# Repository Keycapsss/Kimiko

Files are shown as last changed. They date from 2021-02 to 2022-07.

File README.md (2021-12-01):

# Kimiko





- Aggressive staggered pinky rows
- Support for one rotary encoder per side (two possible positions)
- Per key RGB led with SK6812 Mini-E led (with legs, easy to solder)
- Support for MX switches (Hotswap sockets)

**[Build-Guide](buildguide_en.md)**

**[Keymap-Guide](Keymap.md)**

**Hardware available at [keycapsss.com](https://keycapsss.com)**

Kimiko keyboard with RGB LED

## Parts

Part name | Quantity | Remarks | Photo |
| ------- | -------- | ------- | ----- |
| Kimiko PCB | 1 set ||
| Kimiko case | 1 set | 2 solid panels, 2 with holes for switches (plates) |
| [Pro Micro](https://keycapsss.com/keyboard-parts/parts/79/arduino-pro-micro-atmega32u4-controller) or [Puchi-C](https://keycapsss.com/keyboard-parts/parts/141/puchi-c-pro-micro-replacement-with-usb-c-and-atmega32u4) | 2 pcs (a mix is possible) | Recommend to  use [Mill-Max Single Row Socket Headers](https://keycapsss.com/keyboard-parts/parts/100/single-row-socket-headers-pins-mill-max-series-315), to make it hot-swappable. ||
| Key switch (MX) | 58-60 pcs |  ||
| [Kailh switch socket](https://keycapsss.com/keyboard-parts/parts/49/kailh-hot-swap-pcb-sockets-10-pcs) | 58-60 pcs |  ||
| Diodes 1N4148W (SMD) | 60 pcs |||
| TRRS jack | 2 pcs ||
| Tactile switch | 2 pcs | Reset switch ||
| TRRS cable | 1 cable | Must be a 4-pole cable ||
| Key caps | 58-60 pcs | 1.5U caps, can also be 1U ||
| Micro USB or USB-C cable | 1 pcs | Dependent what you use on the master half. ||

## Optionally

Part name | Quantity | Remarks | Photo |
| ------- | -------- | ------- | ----- |
| [OLED module](https://keycapsss.com/keyboard-parts/parts/80/ssd1306-oled-lcd-display-0.91-inch-128x32-i2c-white) | 2 pcs | It is possible to use only one display ||
| SK6812 Mini-E | 60 pcs |RGB LEDs for keycap backlight **(underglow LEDs must be soldered, because they are connected in series)** ||
| [Rotary encoder](https://keycapsss.com/keyboard-parts/parts/59/rotary-encoder-with-switch) |0-2 pcs| One per side are supported. |
| [Mill-Max Single Row Socket Headers](https://keycapsss.com/keyboard-parts/parts/100/single-row-socket-headers-pins-mill-max-series-315), or [Spring-loaded pin headers](https://keycapsss.com/keyboard-parts/parts/91/spring-loaded-pin-headers-12-pin-2pcs-conthrough), | 4 x 12 row headers | To make pro micro Hot-swappable. Highly recommended to get the header pins too (You can use diode legs if you don't get the header pins)|

## Case files

Drawings (SVG, DXF) for the case are located in the [plates folder](plates/).

## Firmware

Clone/download the QMK firmware and execute the following in the [qmk_firmware](https://github.com/qmk/qmk_firmware) directory to write the default Lily58L keymap

    make keycapsss/kimiko:default:avrdude (for pro micro) 

When **`Detecting USB port, reset your controller now...`** is displayed, press the reset button on the keyboard to start writing.
Each half of the keyboard must be programmed separately using this approach.

If you're using DFU bootloader (in case of the Puchi-C or Elite-C), replace the 'avrdude' with 'dfu'

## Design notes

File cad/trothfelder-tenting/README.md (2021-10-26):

# Kimiko tenting plates

Basically the same as the offical ones with a little extension.

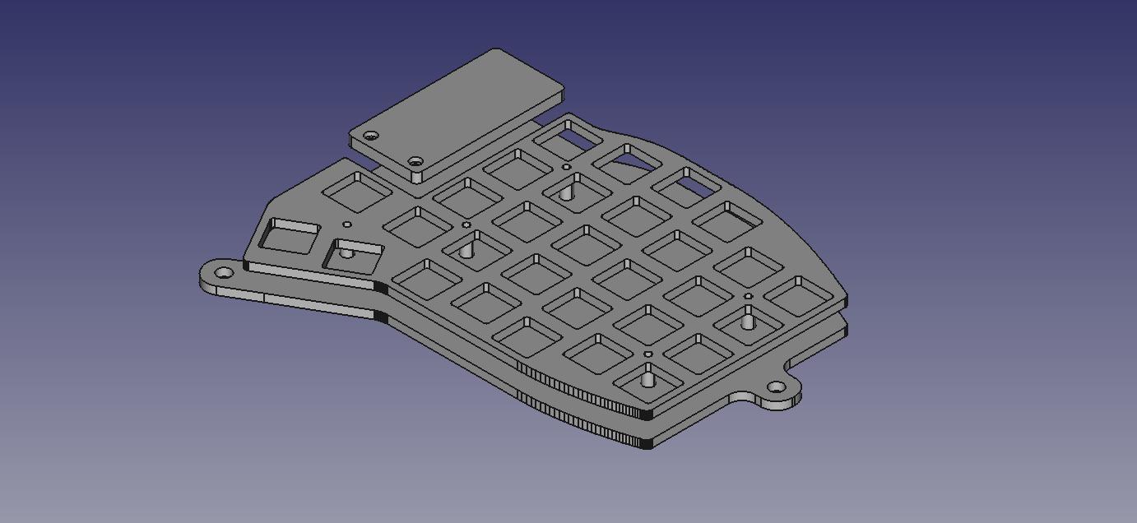
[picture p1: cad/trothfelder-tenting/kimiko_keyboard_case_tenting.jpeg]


The wings on the outside can be use with m5 screws to tent the Kimiko. Adding dipping rubber to the screw heads is a good idea.
I used my cnc mill to cut the plates from 3mm acryllic. The display windowpane is made of 4mm acryllic. In case one wants to cut the windowpane oneself, do not forget to mirror the pane for the second half.
If you want to print the bottom part (the one with the distance holders), do not forget to mirror this part, too. For surface finishing reasons the top part might need to be mirrored in case one wants to print it.
All other parts do not need to be mirrored.

And now a picture of the finished plates:

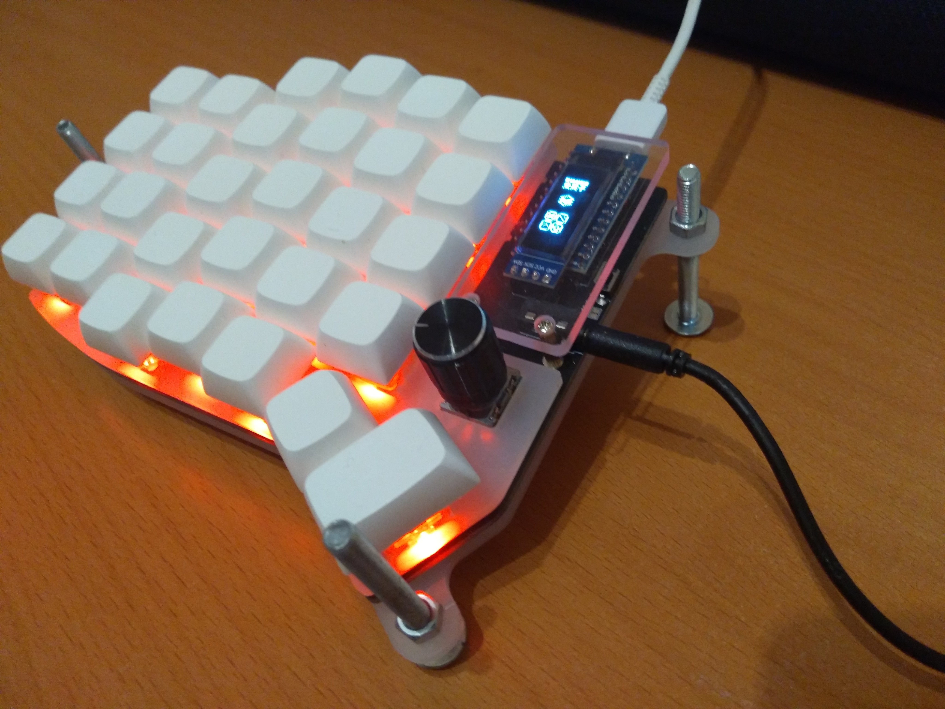
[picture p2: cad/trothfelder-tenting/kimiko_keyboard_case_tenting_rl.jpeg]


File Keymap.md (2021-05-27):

## Default keymap

The [default keymap](https://github.com/qmk/qmk_firmware/blob/master/keyboards/keycapsss/kimiko/keymaps/default/keymap.c) is laid out on the assumption that it will be used in the MacOS/US keyboard environment. Feel free to get creative and experiment with keymaps that match your preferences.

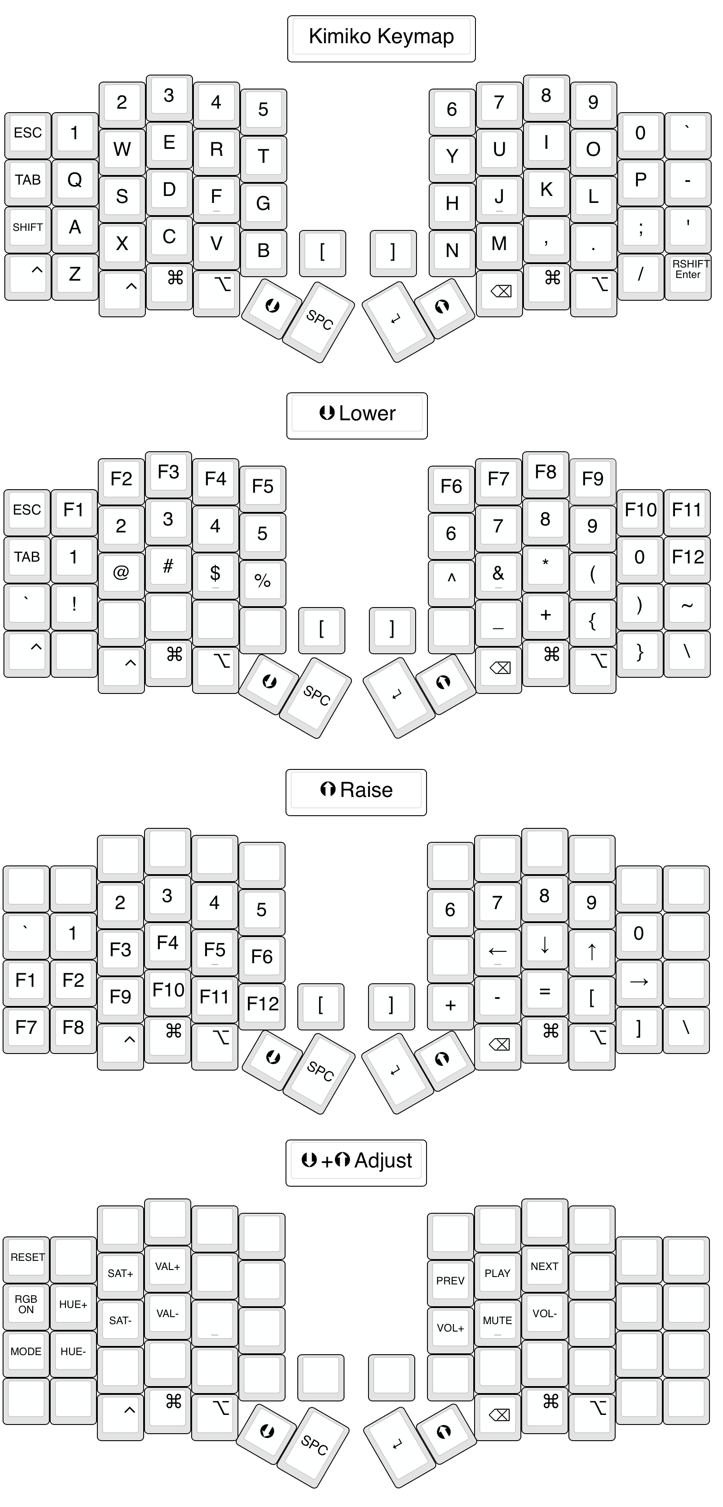
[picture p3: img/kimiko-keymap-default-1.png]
Kimiko default layout


## Customize the default keymap

This self-made keyboard use the QMK firmware, described above. The QMK firmware is highly customizable, and you can unlock a lot functionality simply by editing the keymap.

### Edit keymap.c and customize

When customizing a keymap, start by making a copy of the [`qmk_firmware/keyboards/keycapsss/kimiko/keymaps/default`](https://github.com/qmk/qmk_firmware/blob/master/keyboards/keycapsss/kimiko/keymaps/default/) folder and modifying that directory's internal `keymap.c` file.
Please refer to the [official QMK documentation](https://docs.qmk.fm/#/keycodes) for the key codes and programming specifics.

After changing the keymap,

```bash
make keycapsss/kimiko:default:flash
```

If you get an error, please double-check the board, connection and command.

### Bootloader

**Pro Micro and Puchi-C/Elite-C have different bootloader.** Edit the `rule.mk` file in your keymap folder and add the following line to it.

#### Puchi-C or Elite-C

```c
BOOTLOADER = atmel-dfu
```

#### Pro Micro

```c
BOOTLOADER = caterina
```

If you use the command `make keycapsss/...:flash`, it read the bootloader settings from the `rule.mk` and uses the right flashing software.
If you don't have set the `BOOTLOADER` setting, you can change the command to `make keycapsss/...:caterina` for Pro Micro, or `make keycapsss/...:dfu` for Puchi-C/Elite-C

More information on the [official QMK site](https://beta.docs.qmk.fm/using-qmk/guides/flashing/flashing#atmel-dfu).

### Handedness by EEPROM

You can tell each side of the Keyboard, whether it's left or right, by writing it into it's eeprom.  
In order to do so, first put `#define EE_HANDS` into your config.h.
Then flash the keymap with

```bash
make keycapsss/kimiko:(yourkeymap):avrdude-split-left 
```

and

```bash
make keycapsss/kimiko:(yourkeymap):avrdude-split-right
```

respectively.
If you're using DFU bootloader (in case of the Puchi-C), replace the `avrdude` with `dfu`

From then on, your keyboard will know, which side they are, no matter which side you plug in. You won't have to use the flags again when flashing an update of your keymap.

If you have any problems that aren't answered here, consider joining our discord server at: (<https://discord.gg/5Vfa9azMUr>)

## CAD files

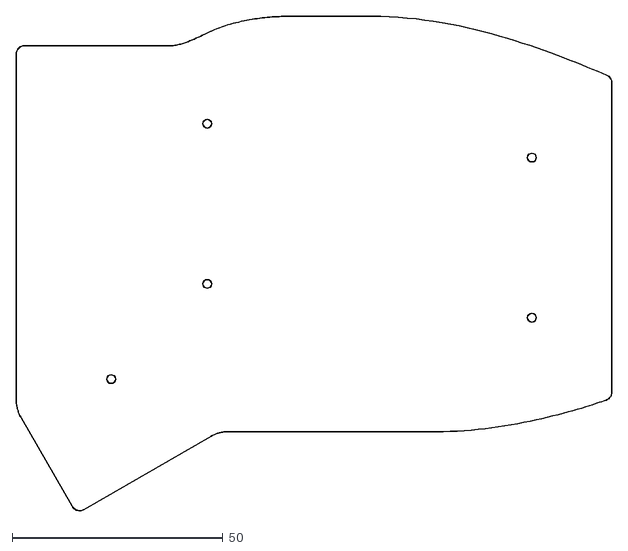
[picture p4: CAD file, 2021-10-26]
cad/benroe-standard-plates/kimiko-plate-bottom.dxf
141.3 x 117.2

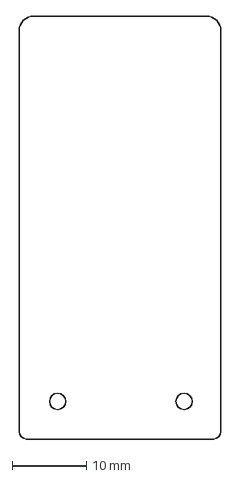
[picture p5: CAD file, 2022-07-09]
cad/plate-guard.dxf
27.3 x 57.1 mm

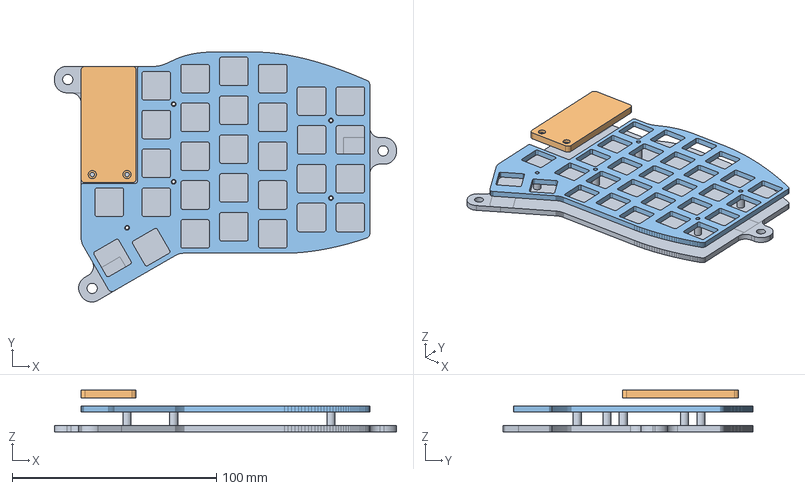
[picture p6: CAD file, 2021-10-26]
cad/trothfelder-tenting/kimiko_keyboard_case_tenting.FCStd
167.4 x 122.4 x 20.4 mm
Bottom
Display
Top

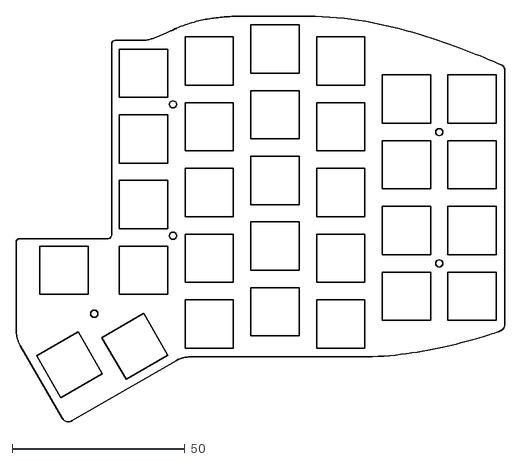
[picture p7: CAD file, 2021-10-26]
cad/benroe-standard-plates/kimiko-plate-top.dxf
141.3 x 117.2

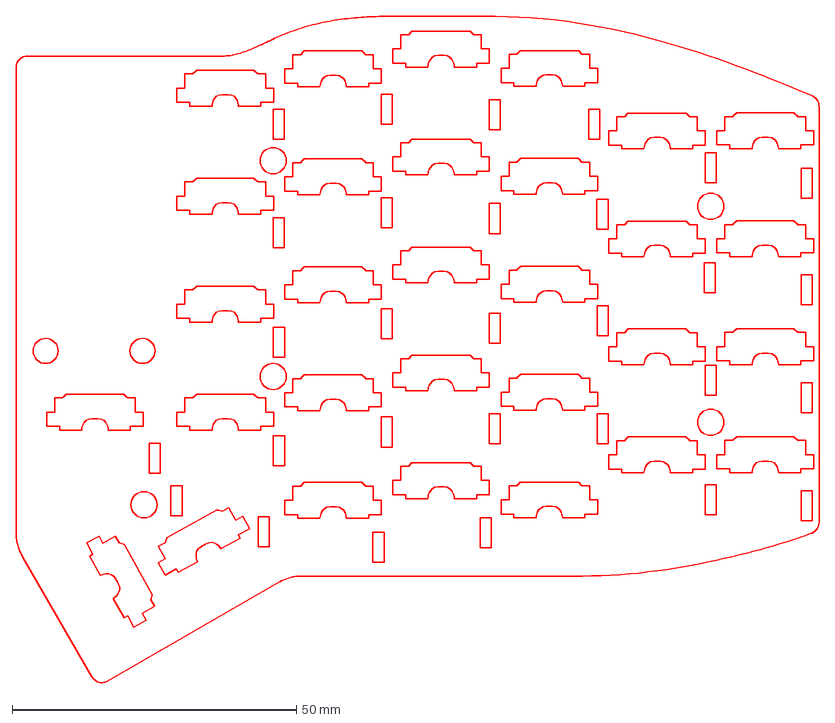
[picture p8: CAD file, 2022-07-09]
cad/foam-bottom.dxf
141.3 x 117.2 mm

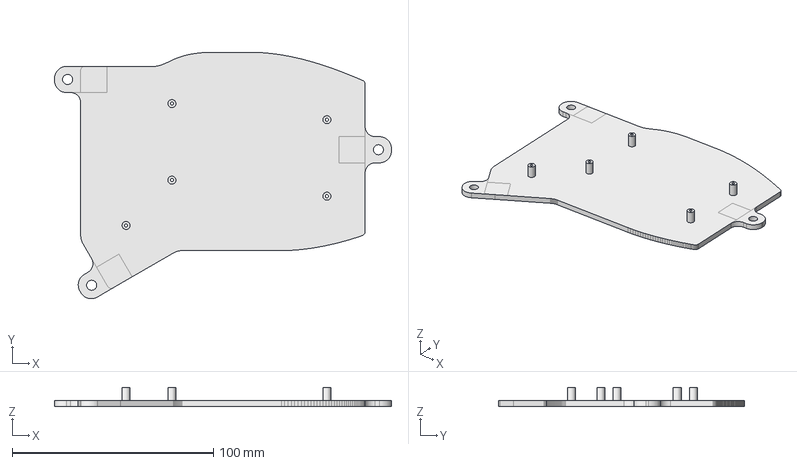
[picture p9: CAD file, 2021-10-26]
cad/trothfelder-tenting/kimiko_keyboard_case_tenting_PartBottom.step
167.4 x 122.4 x 9.60 mm

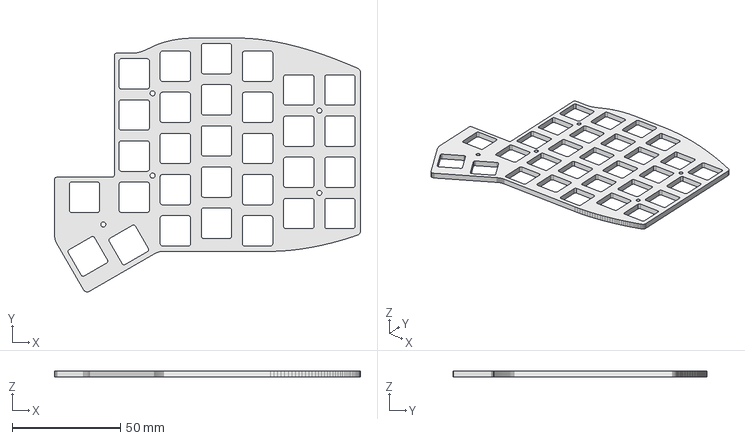
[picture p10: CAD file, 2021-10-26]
cad/trothfelder-tenting/kimiko_keyboard_case_tenting_PartTop.step
141.3 x 117.2 x 3.00 mm

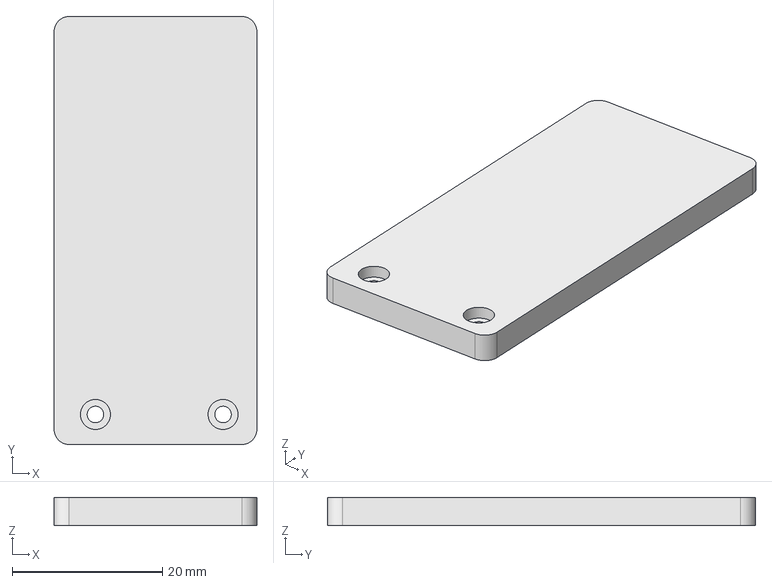
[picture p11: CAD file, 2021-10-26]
cad/trothfelder-tenting/kimiko_keyboard_case_tenting_PartDisplay.step
27.0 x 57.0 x 3.75 mm

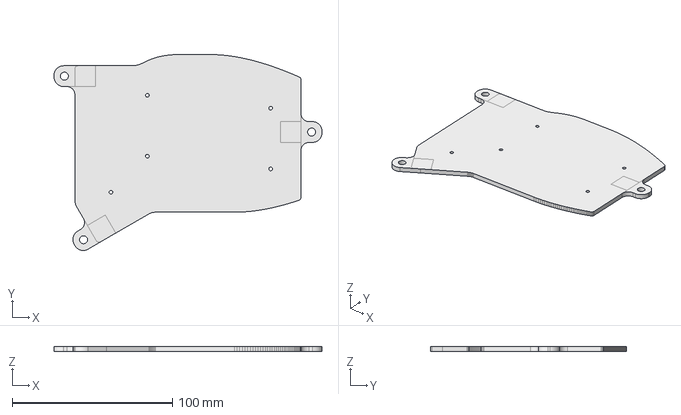
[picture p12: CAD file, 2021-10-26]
cad/trothfelder-tenting/kimiko_keyboard_case_tenting_PartBottom2.step
167.4 x 122.4 x 3.00 mm

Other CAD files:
cad/trothfelder-tenting/kimiko_keyboard_case_tenting.stl
cad/trothfelder-tenting/kimiko_keyboard_case_tenting_PartBottom.stl
cad/trothfelder-tenting/kimiko_keyboard_case_tenting_PartBottom2.stl
cad/trothfelder-tenting/kimiko_keyboard_case_tenting_PartDisplay.stl
cad/trothfelder-tenting/kimiko_keyboard_case_tenting_PartTop.stl

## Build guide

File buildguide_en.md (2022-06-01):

# Kimiko Build Guide





## Required tools

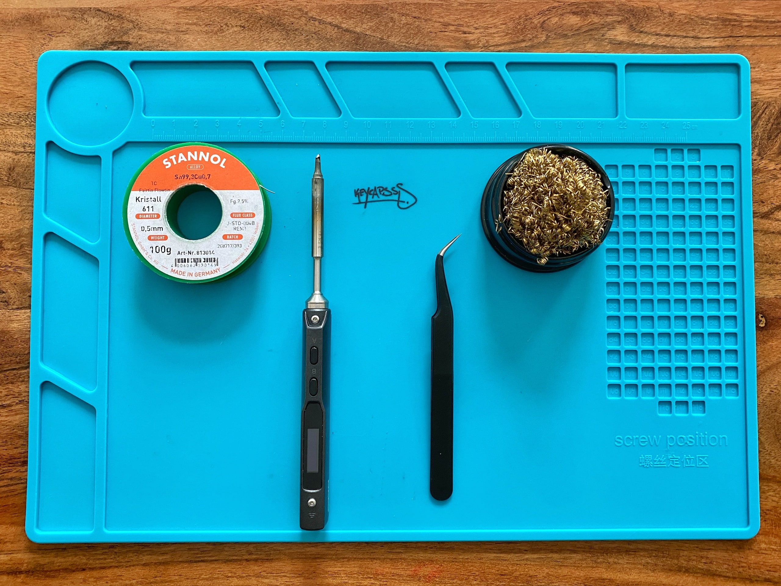
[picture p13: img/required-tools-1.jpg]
Required tools for soldering


* Soldering iron with adjustable temperature
* Solder (i use Sn99.3Cu0.7 0.5mm/0.02inch)
* Tweezers for the small SMD parts
* Tip cleaner (wet sponge or brass wool)
* Side cutters/flush cutters
* Fine pliers

Most parts I solder at 320-340°C. The SMD LEDs are temperature sensitive, so lower the temperature to 300-320°C.

### How to solder tips

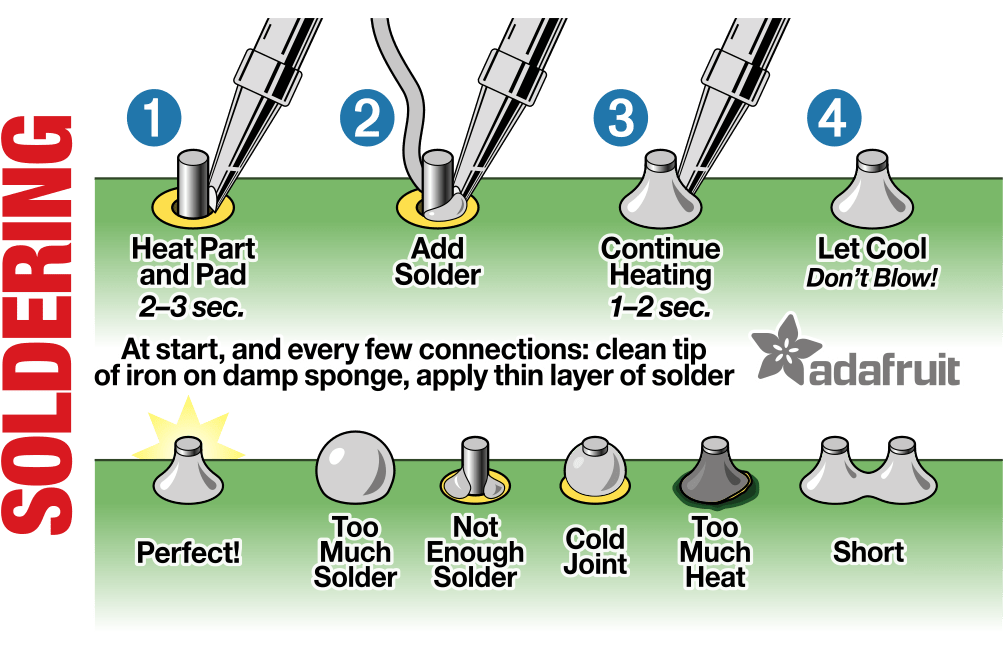
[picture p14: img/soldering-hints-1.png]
How to THT soldering

*[adafruit](https://github.com/adafruit/Reference-Cards)  CC-BY-SA 4.0*

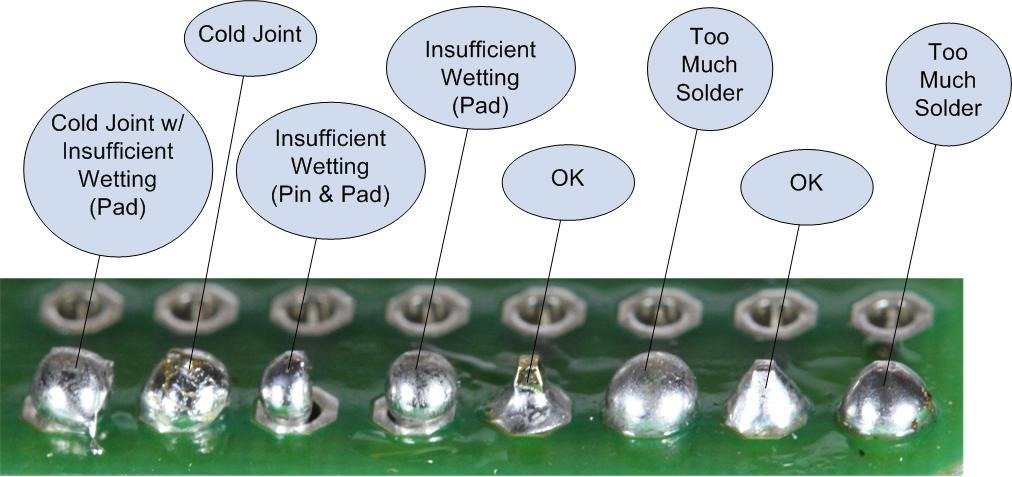
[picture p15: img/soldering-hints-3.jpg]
How to THT soldering

*Source: [adafruit](https://learn.adafruit.com/adafruit-guide-excellent-soldering/common-problems)*

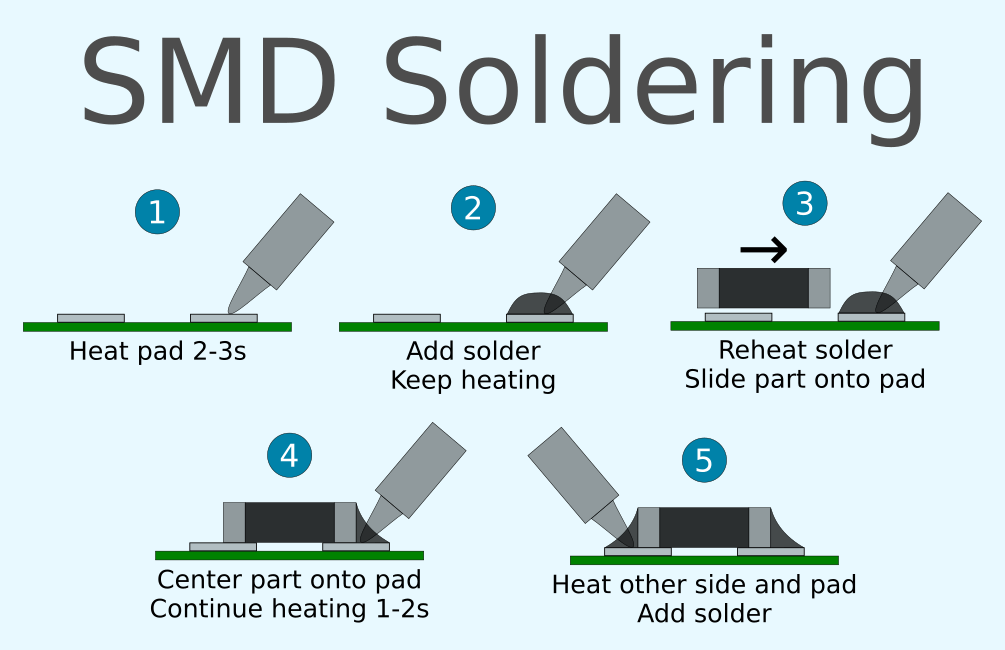
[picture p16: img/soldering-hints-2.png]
How to SMD soldering

*[Timo Schindler](https://github.com/marove2000/referenceCards)  CC-BY-SA 4.0*

## BOM

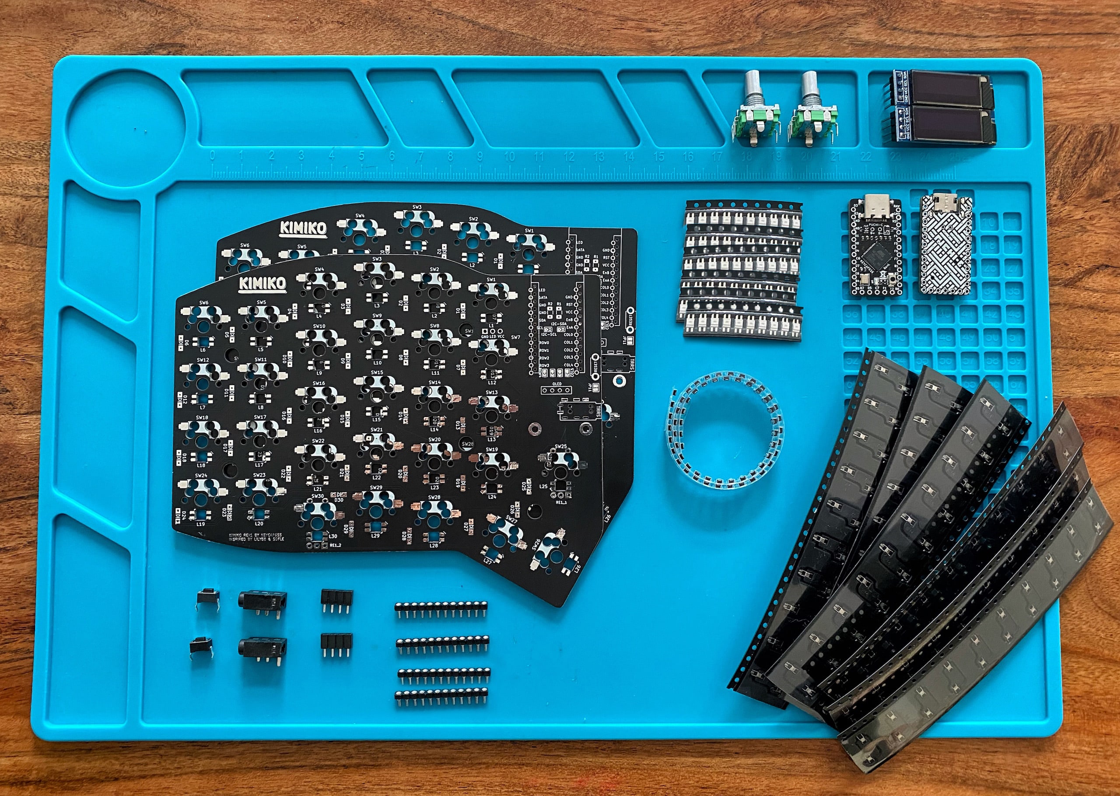
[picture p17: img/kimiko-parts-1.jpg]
Kimiko Parts


### Required parts

Part name | Quantity | Remarks | Photo |
| ------- | -------- | ------- | ----- |
| Kimiko PCB | 2 pcs | PCB is reversible |
| Kimiko case | 1 set | 2 solid panels, 2 plates, and screws/spacer |
| [Pro Micro](https://keycapsss.com/keyboard-parts/parts/79/arduino-pro-micro-atmega32u4-controller) or [Puchi-C](https://keycapsss.com/keyboard-parts/parts/141/Puchi-C-pro-micro-replacement-with-usb-c-and-atmega32u4) | 2 pcs (a mix is possible) | I highly recommend, use [Mill-Max Single Row Socket Headers](https://keycapsss.com/keyboard-parts/parts/100/single-row-socket-headers-pins-mill-max-series-315), or [Spring-loaded pin headers](https://keycapsss.com/keyboard-parts/parts/91/spring-loaded-pin-headers-12-pin-2pcs-conthrough), to make it Hot-swappable. ||
| Key switch (MX) | 58-60 pcs | 60 if you do not install the rotary encoder. 3-Pin and 5-Pin switches are supported.  ||
| [Kailh MX switch socket](https://keycapsss.com/keyboard-parts/parts/49/kailh-hot-swap-pcb-sockets-10-pcs) | 58-60 pcs |  ||
| Diodes 1N4148W (SMD SOD-123/SOD-123FL) | 60 pcs |||
| TRRS jack | 2 pcs ||
| Tactile switch | 2 pcs | Reset switch ||
| TRRS cable | 1 cable | Must be a 4-pole cable ||
| Key caps | 58-60 pcs | Keycap for the thumb switch can be a 1.5U, or a 1U keycap. ||
| Micro USB or USB-C cable | 1 pcs | Dependent what you use on the master half (Pro Micro = Micro USB / Puchi-C = USB-C). ||

### Optionally parts

Part name | Quantity | Remarks | Photo |
| ------- | -------- | ------- | ----- |
| [Rotary encoder](https://keycapsss.com/keyboard-parts/parts/59/rotary-encoder-with-switch) |0-2 pcs| One per side are supported. |
| [OLED 0.91 module](https://keycapsss.com/keyboard-parts/parts/80/ssd1306-oLED-lcd-display-0.91-inch-128x32-i2c-white) | 0-2 pcs | It is possible to use only one display. ||
| [SK6812 Mini-E LEDs](https://keycapsss.com/keyboard-parts/parts/114/sk6812-mini-e-rgb-smd-LED) | 60 pcs |RGB LEDs for the keycap backlight. **Also the LEDs under the encoder must be soldered, because they are wired in series.** ||
| [Mill-Max Single Row Socket Headers](https://keycapsss.com/keyboard-parts/parts/100/single-row-socket-headers-pins-mill-max-series-315), or [Spring-loaded pin headers](https://keycapsss.com/keyboard-parts/parts/91/spring-loaded-pin-headers-12-pin-2pcs-conthrough), | 4 x 12 row headers | To make pro micro Hot-swappable. Highly recommended to get the header pins too (You can use diode legs if you don't get the header pins)|

## Introduction

**Note: please be careful, as the case will be scratched if it hits or rubs a hard thing after assembly.**

This PCB is reversible. We will mount parts **on each side.**

Mark the surface with masking tape to make it easy to keep track of the back and front of each board.

The pictures in this guide show the PCB for the left side.

## Attach the diodes

The diodes are mounted on the **back side** of the board.

Pay attention to orientation, diodes are polarized. If the orientation is incorrect, the key will not respond.

Solder the diode as shown in the following figure.

SMD Diode orientation

Apply preliminary solder (melt a small amount on the substrate/"tin the pad") on one pad of the PCB diode.

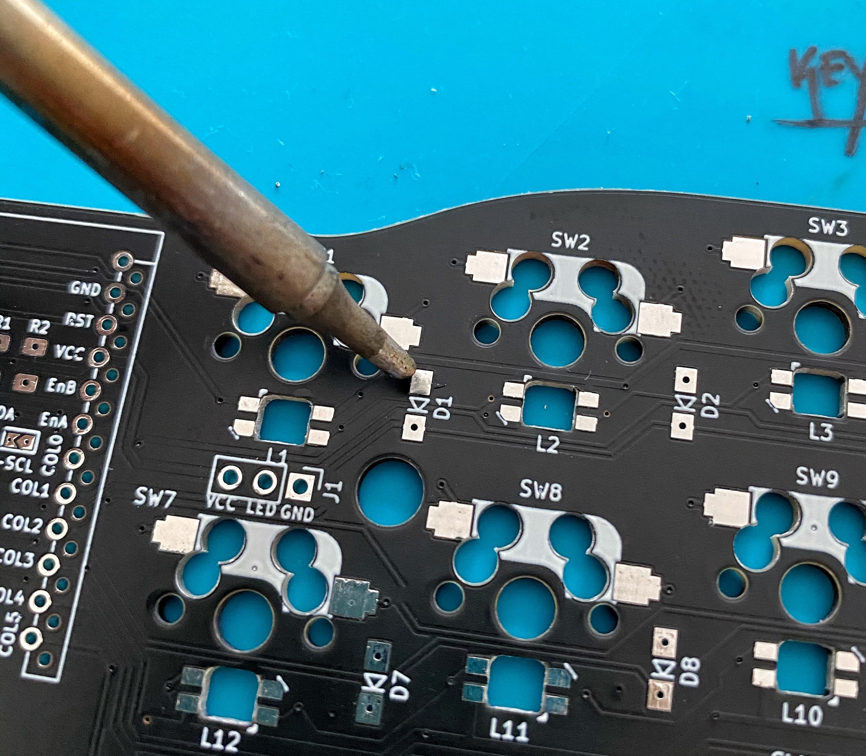
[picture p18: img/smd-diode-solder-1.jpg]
SMD diode orientation

*PCB back side (left half)*

Then use tweezers to slide the diode into position, whilst you heat the pre-soldered pad.
Remove the soldering iron and allow to cool, whilst still holding the diode.

Then solder the remaining side.  
When all diodes have been soldered, check for missing spots.

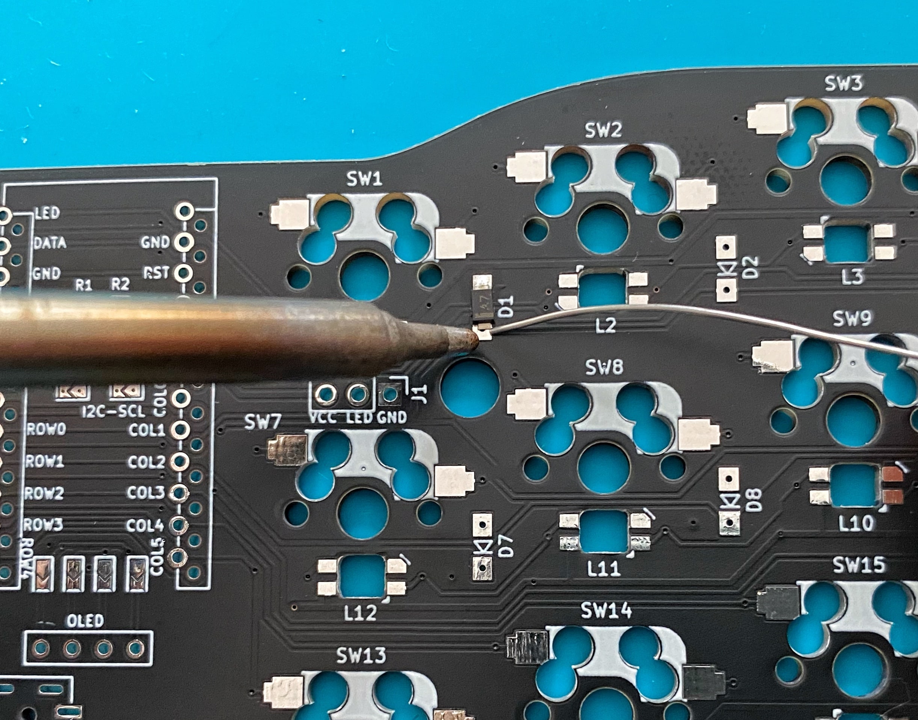
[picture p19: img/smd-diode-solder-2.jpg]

*PCB back side (left half)*

You can use a multimeter in "diode mode", on the front side of the board to ensure that the solder connections are good and that the orientation of the diodes is correct.

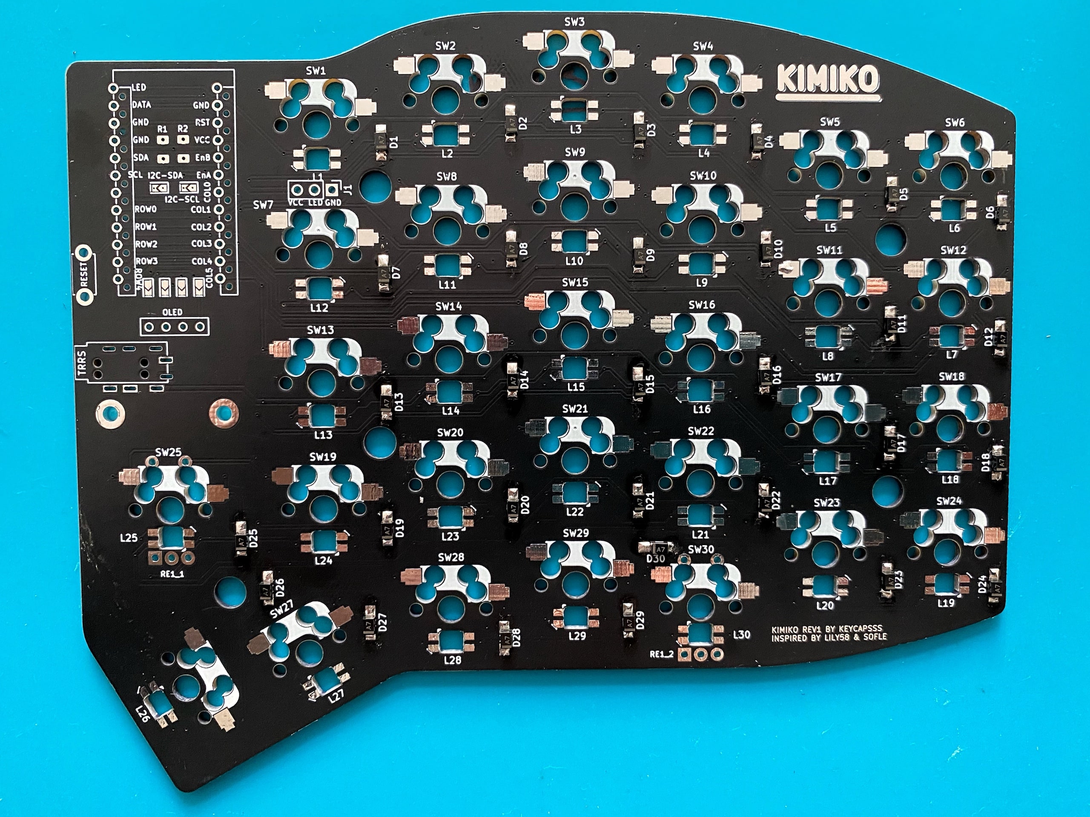
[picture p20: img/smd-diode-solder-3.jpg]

*All diodes soldered on back side (left half)*

## Solder the LEDs for keycap back (optionally)

Solder the SK6812 Mini-E LEDs (with legs), on the **back side** of the board.  
**Pay attention to orientation of the LEDs** (the angled leg of the led should be soldered to the pad of the PCB with the slanted white mark)**.**

We solder LEDs using the same approach as for the diodes.
Begin by pre-soldering one side of the LED pad.

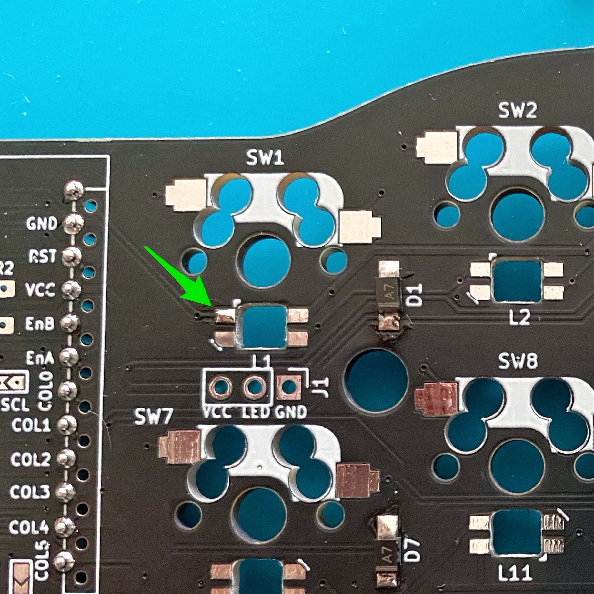
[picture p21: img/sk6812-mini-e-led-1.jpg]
SK6812 Mini-E soldering


Place the component, and hold it in place with tweezers.  

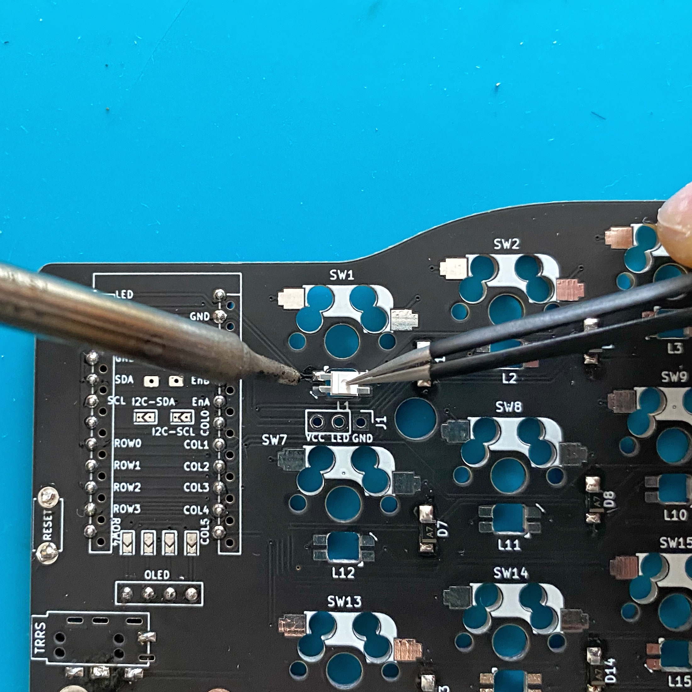
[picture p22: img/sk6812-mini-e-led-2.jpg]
SK6812 Mini-E soldering


Then solder the other pads.

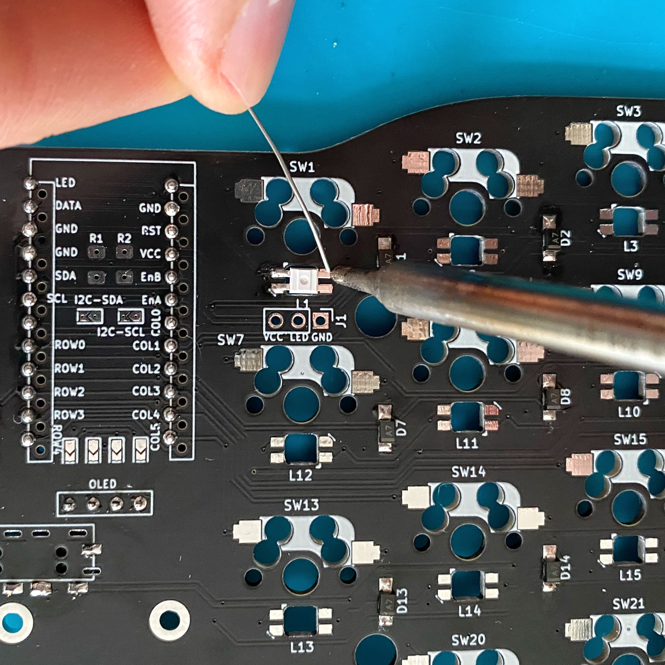
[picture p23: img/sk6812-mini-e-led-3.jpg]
SK6812 Mini-E soldering


**It is necessary to solder all LEDs, even if you use the rotary encoder.**

For the LEDs it's important to keep the heating as short as possible. Try to not touch the plastic of the LED itself with the iron but only the the metal legs. Use flux if you are having difficulty.
The LEDs are connected in series. If a LED is broken or has bad solder connections, the following LEDs will either not light up at all or will light up in a different color than the default (red).
Doublecheck the last LED that lights up properly and the first that doesn't.  
On the LEDs with legs it's easily possible to get a loose connection.

## Soldering the TRRS jack and reset switch

The TRRS jack and the reset switch are mounted on the **front side** (opposite side of diodes).
Attach the parts and fix them temporarily with masking tape. Turn over the board and solder the pins, making sure that the TRRS jack and reset switch are in firm contact with the board.

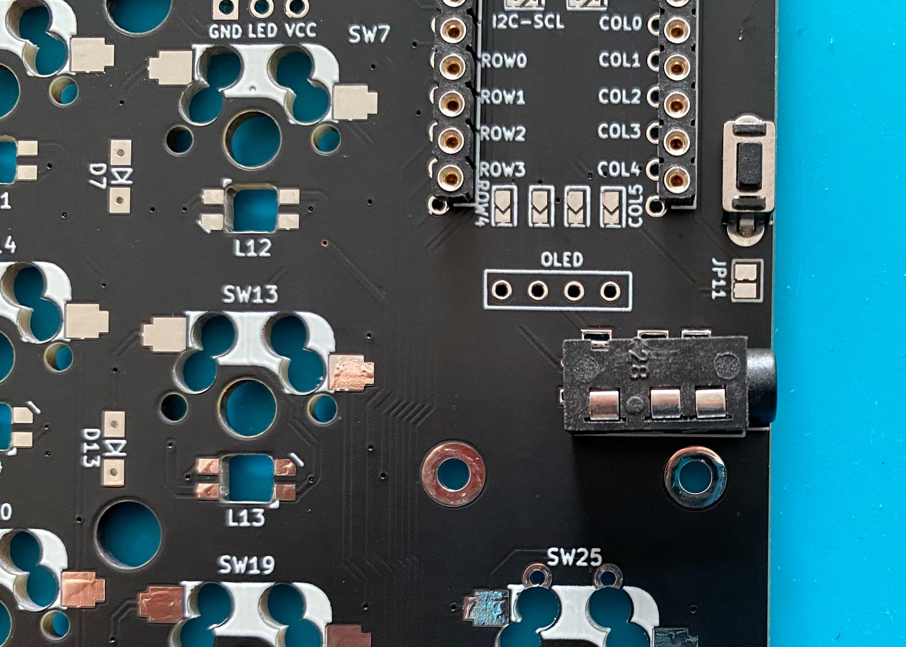
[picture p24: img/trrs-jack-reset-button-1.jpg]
TRRS jack and reset button

*PCB front side (left half)*

**Be careful** Double check your part orientation before you commit to soldering. A mistake here can mean painful desoldering experiences.

## Attach the OLED socket

On the **front side** of the board, apply enough solder to bridge the four jumper terminals in the Pro Micro section.

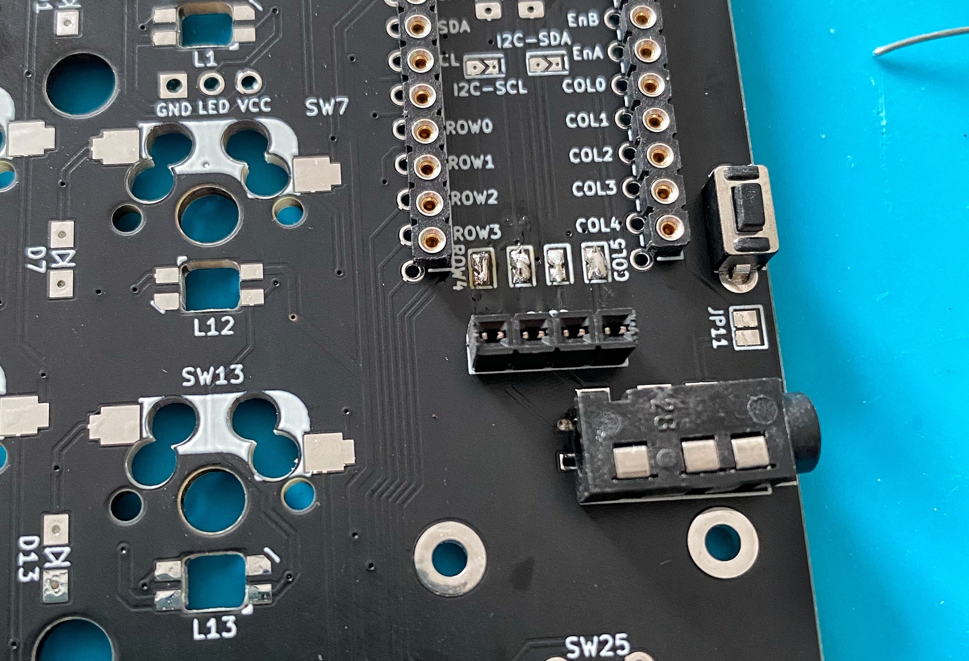
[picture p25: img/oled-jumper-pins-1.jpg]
Oled jumper pads

*PCB front side (left half)*

Attach the connector for the OLED on front side (opposite side of diodes). Be careful to avoid adding a lot of solder, as it is easy for solder to flow into the connector. Make sure it is straight and at a right-angle to the PCB.

## Install Pro Micro (with sockets)

### Check Pro Micro by flashing

**Before installing the Pro Micro, no matter which (can also happen on the Puchi-C), check whether they are working by plugging them in and [flashing the default keymap](#flash-keymap-on-pro-micropuchi-c).**

Open [QMK Toolbox](https://github.com/qmk/qmk_toolbox/releases/latest) and connect your Pro Micro/Puchi-C to the computer.  
If your Pro Micro/Puchi-C is complete new (without a firmware on it), a message *"***Atmel DFU device connected: ..."* should appear.  

If the message does not appear, press the reset button on the Puchi-C, or short RST & GND pins on the Pro Micro to bring it into the DFU mode. (For first timers you can short using a wire and touching an end each to RST & GND pins while the pro micro is plugged in)
If the message appears, the device should be working correctly.

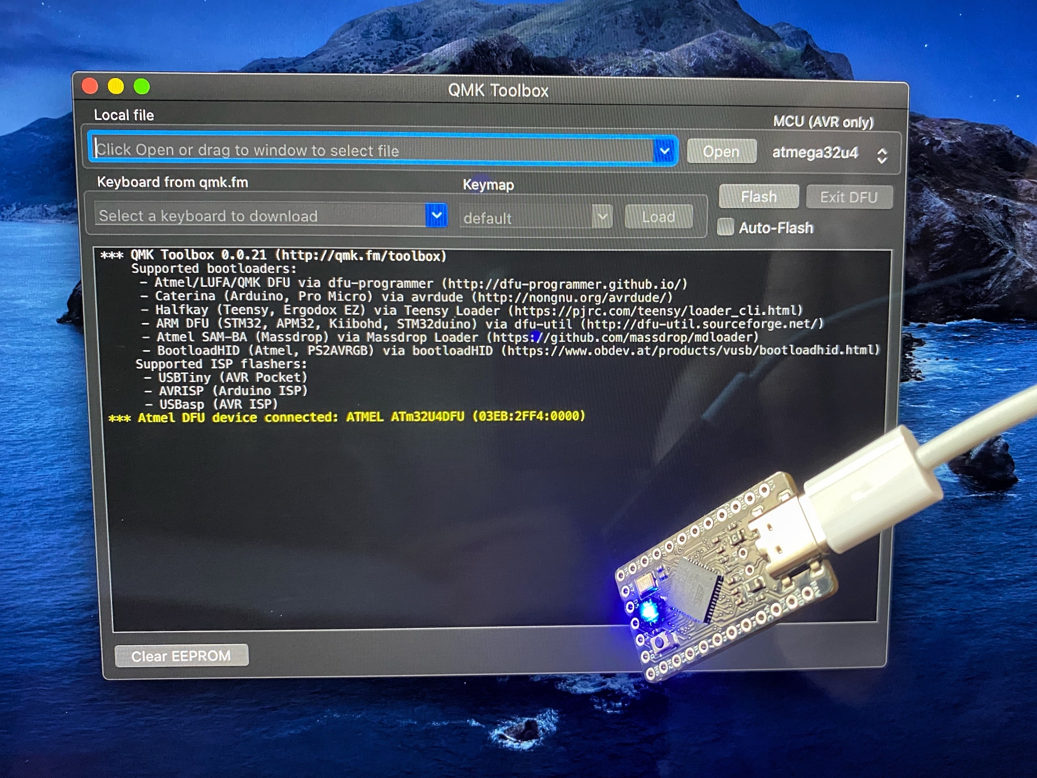
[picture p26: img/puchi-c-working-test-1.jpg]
QMK toolbox


### Install onto PCB

You have 3 options:

* Use the pin headers enclosed in the bag of Pro Micro
* Use Mill-Max sockets and Mill-Max headers
* Use Mill-Max sockets with diode legs

For other ways to mount your Pro Micros, look at [the crkbd build guide.](https://nicedoc.io/foostan/crkbd/blob/master/corne-classic/doc/buildguide_en.md#using-pin-sockets)

### Using Pin header enclosed

The pin header enclosed in the bag of Pro Micro can be used. But I highly recommend using the Mill-Max socket headers, or Spring-loaded pin headers. With the Mill-Max header it's easier to replace the Pro Micro, if it's broken. (Especially the Pro Micros- the USB port will break at some point!)

Standard header/ Mill-Max socket header
*Standard headers vs Mill-Max sockets. Note the standard header pins will NOT fit into the Mill-Max sockets. You have to get Mill-Max headers or use diode legs*

1. Note the **outlined sets of holes in PCB,** and insert the Standard header into the outlined holes on the **front side**. Please be careful, as the **connections are different for the right and left boards.** See the image in step 1 of [Mill-Max section](#use-mill-max-sockets-and-mill-max-headers) for a reference.
2. Solder the Standard header from the **back side** and pay attention to not creating solder bridges between the different sets of holes.
3. Place the Pro Micro/Puchi-C on top of the headers on the **Front side**. **(USB socket facing down)**.
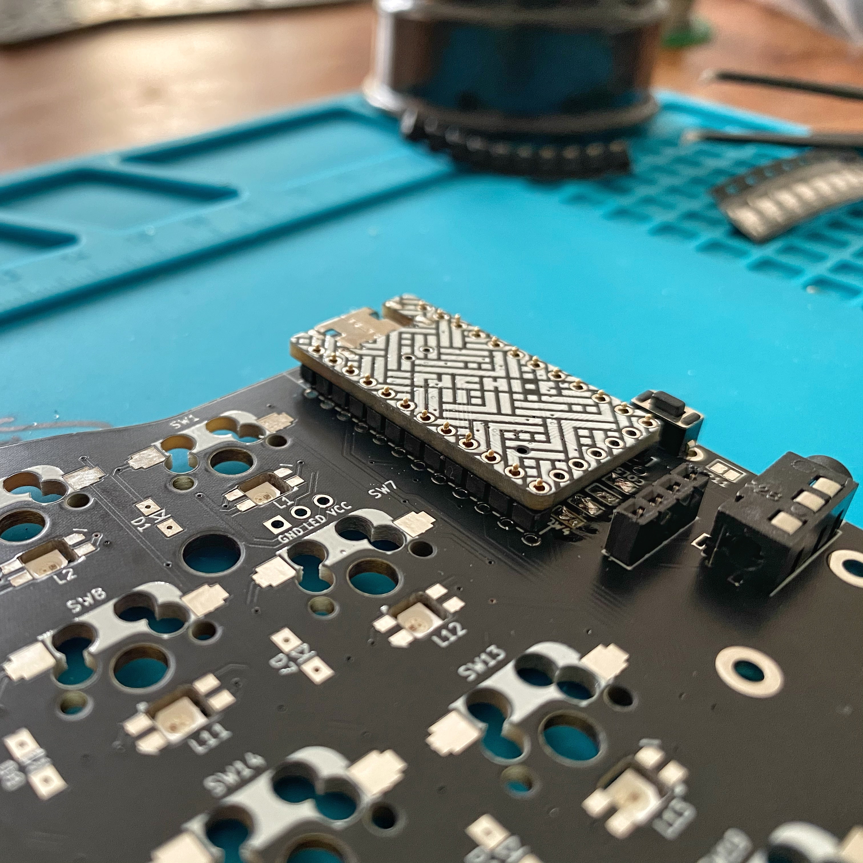
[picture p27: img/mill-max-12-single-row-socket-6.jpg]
Mill-Max sockets

4. Solder the Pro-Micro in place

Go to [Install the OLED on the socket](#install-the-oled-sd1306-on-the-socket)

### Use Mill-Max sockets and Mill-Max headers

1. Note the **outlined sets of holes in PCB,** and insert the Mill-Max sockets into the outlined holes on the **front side**. Please be careful, as the **connections are different for the right and left boards.**
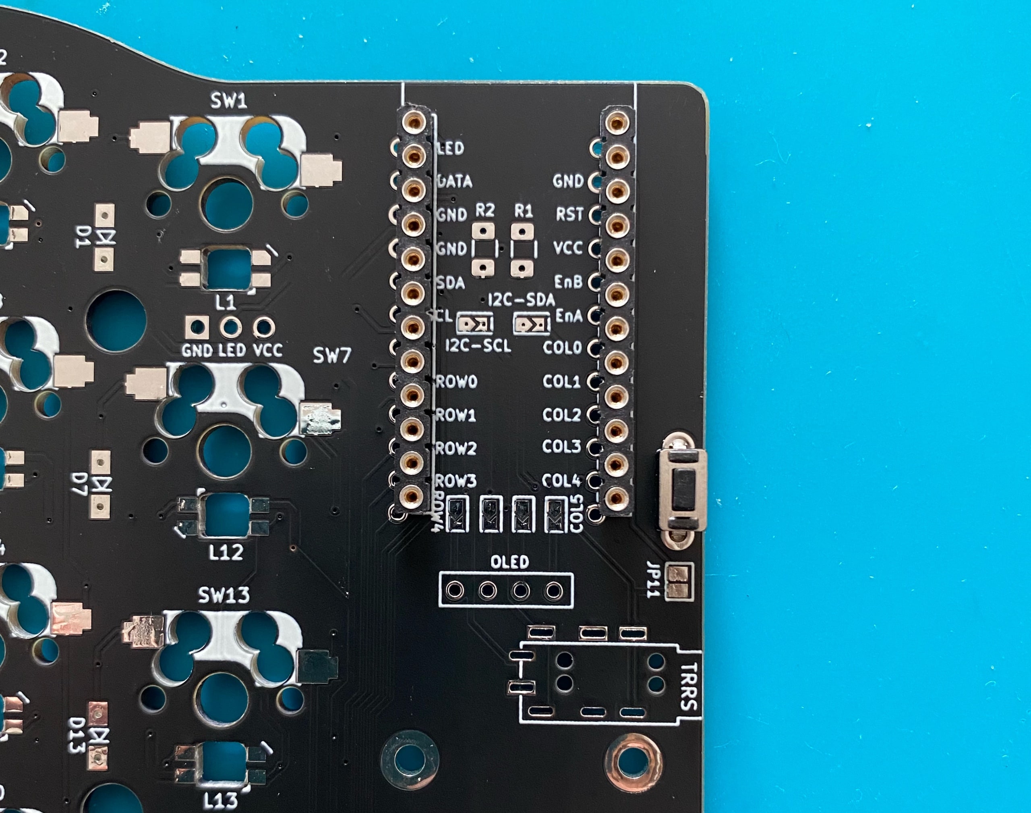
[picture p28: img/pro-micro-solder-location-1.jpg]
Pro Micro_PCB

*PCB front side (left half)*
2. Solder the Mill-Max sockets from the **back side** and pay attention to not creating solder bridges between the different sets of holes.
3. Insert the Mill-Max pins with pliers into the sockets.
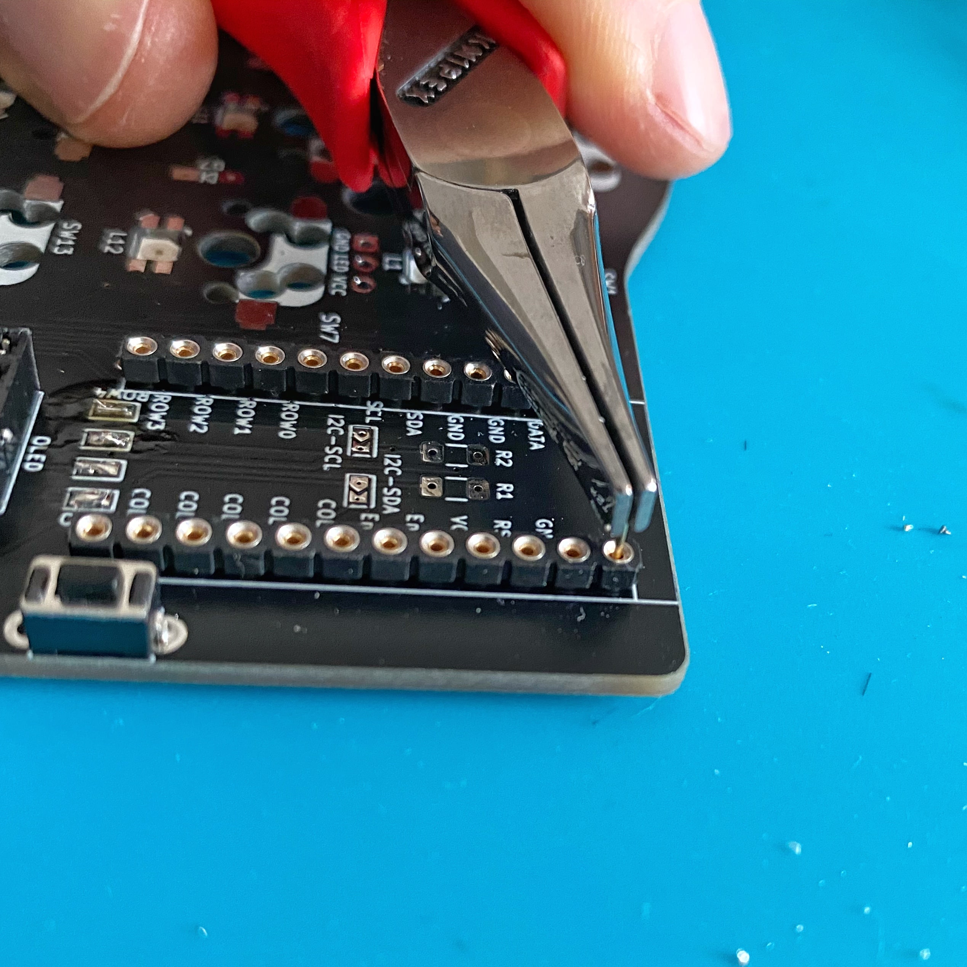
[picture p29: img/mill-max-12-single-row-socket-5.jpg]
Mill-Max sockets

*Example image with Mill-Max sockets*
4. Place the Pro Micro/Puchi-C on top of the headers on the **Front side**. **(USB socket facing down)**.
Punchi-C Placement
*Puchi-C Placement*
5. Solder the pins.

Go to [Install the OLED on the socket](#install-the-oled-sd1306-on-the-socket)

### Use Mill-Max sockets with diode legs

1. Note the **outlined sets of holes in PCB,** and insert the Mill-Max sockets into the outlined holes on the **front side**. Please be careful, as the **connections are different for the right and left boards.**
Pro Micro_PCB
*PCB front side (left half)*
2. Solder the Mill-Max sockets from the **back side** and pay attention to not creating solder bridges between the different sets of holes.
3. Optional but highly recommended: Cover the sockets with heat resistant tape (scotch tape or electrical tape). This will prevent the solder seeping into the sockets which will make it practically impossible to remove the pro-microsocket
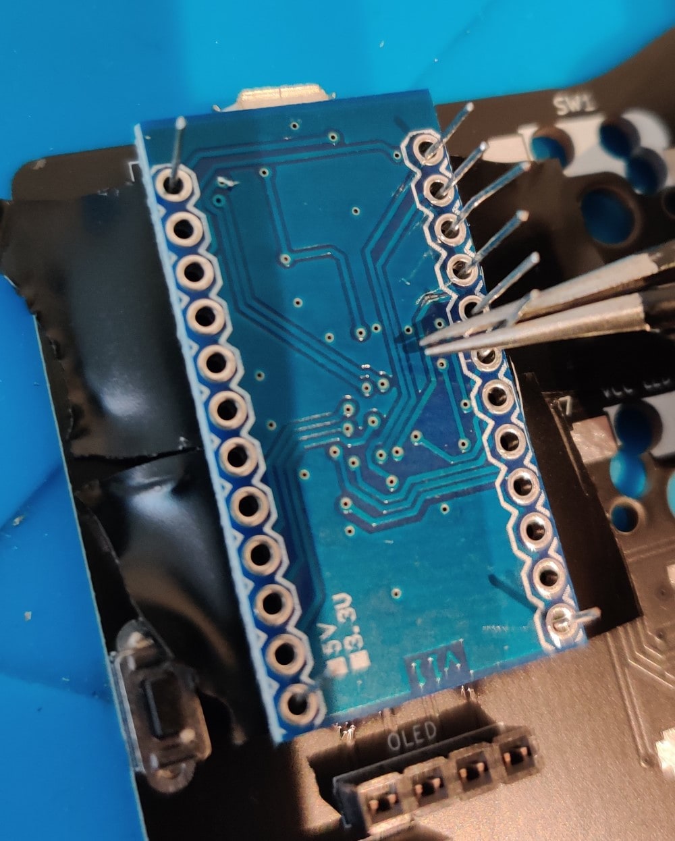
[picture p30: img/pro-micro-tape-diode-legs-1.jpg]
Pro Micro with tape

*Example with tape*
4. Insert the diodes legs with pliers or tweezers into the sockets. You should hear/feel 2 'clicks' Once when it puches through the tape and the second when it engages into place on the Max-Mill socket. Do not use your hands as the diode legs can be sharp
Mill-Max sockets
*Example image with diode legs*
5. Place the Pro Micro/Puchi-C **(USB socket facing down)**.
Diode legs 1
*Pro Micro placement with diode legs*
6. Solder the pins. Shorten the pins with side cutters/flush cutters
Diode legs 2
*Time to snip*
7. You should be able to slowly wedge off the pro micro from the Max-Mill sockets using tweezers and a bit of levering from the top and bottom of the pro micro. Take off the tape.
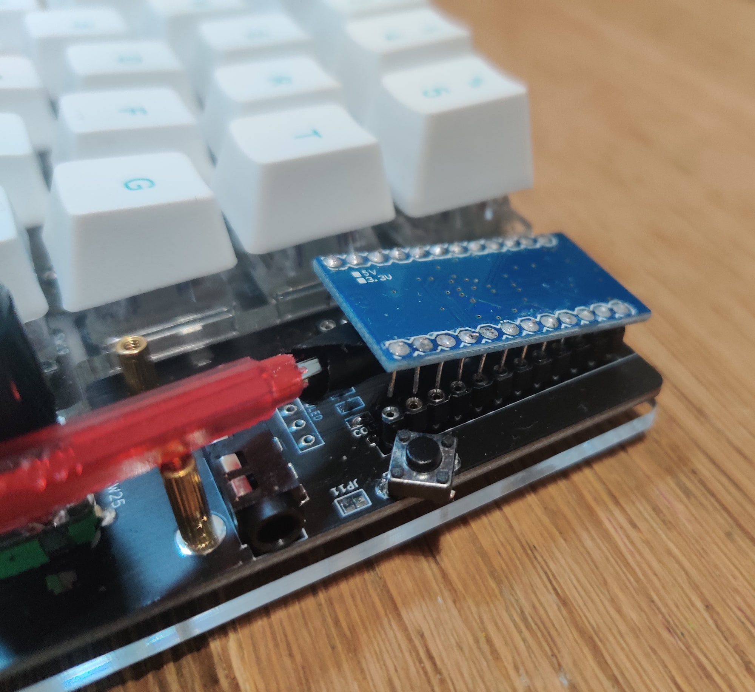
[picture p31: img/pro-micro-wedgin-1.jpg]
Pro Micro Removed

*Pro Micro levered off the pins. Now time to remove tape*

## Install the OLED (SD1306) on the socket

Remove the black plastic spacer that's part of the header installed in the OLED. Then you'll be able to shorten it's legs with your pliers and put them into the socket, resulting into a way more low profile OLED. You can wiggle it off with pliers carefully.

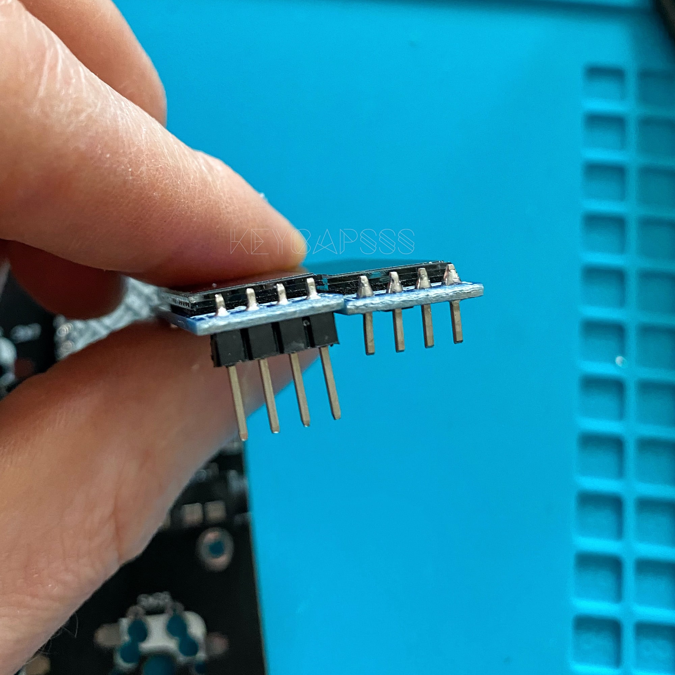
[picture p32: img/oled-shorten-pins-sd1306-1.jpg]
Oled SD1306 shorten pins
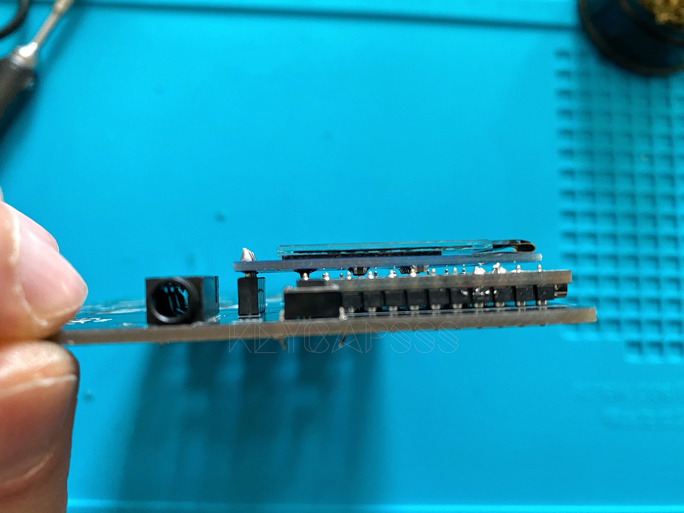
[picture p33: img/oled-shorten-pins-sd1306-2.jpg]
Oled SD1306 shorten pins
 

## You have reached a checkpoint

Plug your keyboard (**do not plug-in or remove the TRRS cable, while a Pro Micro is connected via USB**), look what happens, solve problems, be happy if there are none (if you followed all the steps your pro micros should have [firmware](#flash-keymap-on-pro-micro) at this point).  

By now you can also checked whether all switches will be able to work. In order to do so, open the [QMK Test Site](https://config.qmk.fm/#/test), short the pads on which the kailh sockets will be installed (next step) with tweezers.

See [Troubleshooting](#troubleshooting) if anything is not working

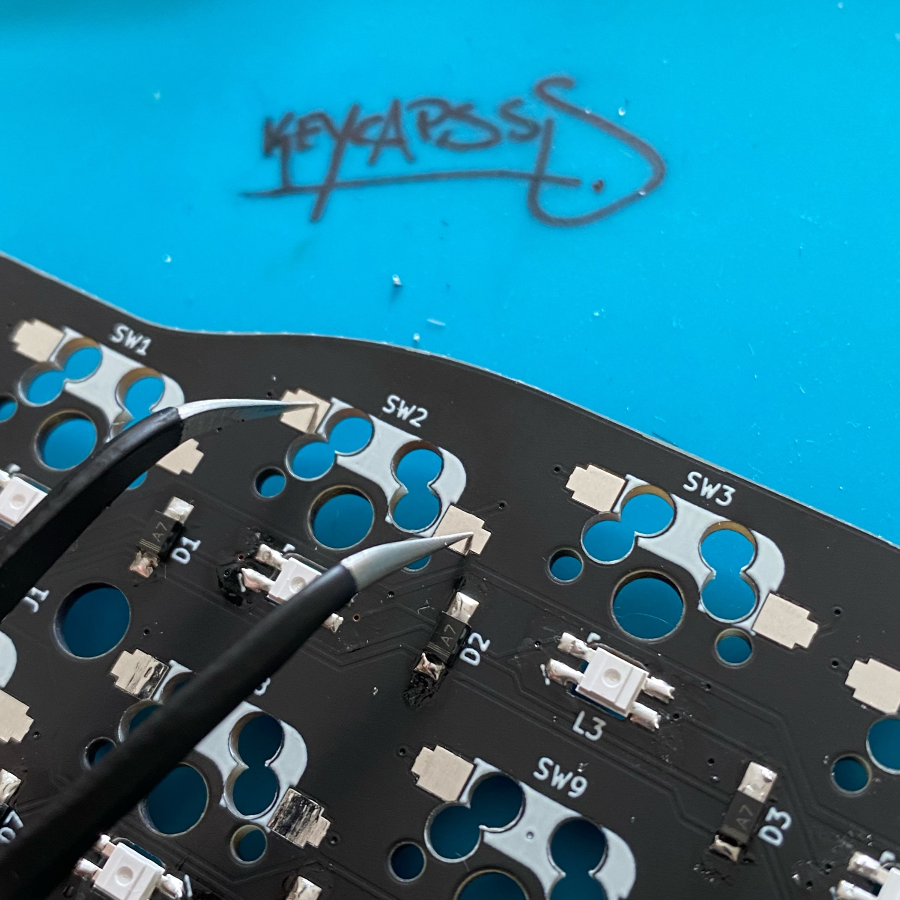
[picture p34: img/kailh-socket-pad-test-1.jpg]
Tweezers test switch


## Solder the sockets

The sockets are mounted on the **back side**, the same side as the diodes.

Much like the approach used for the diodes above, begin by pre-soldering one side of the socket pad.

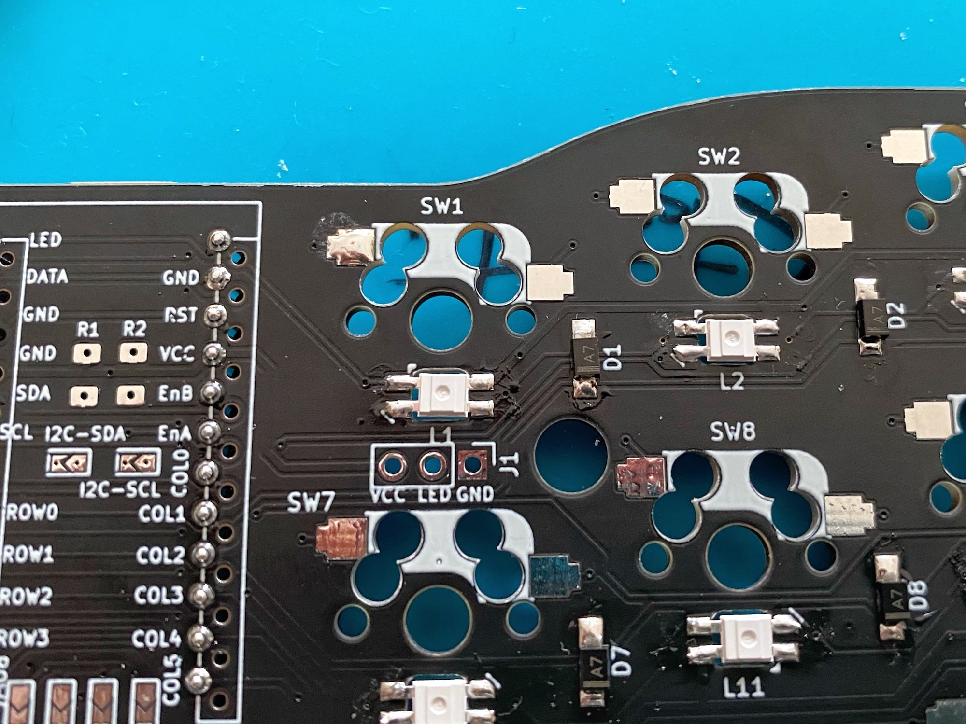
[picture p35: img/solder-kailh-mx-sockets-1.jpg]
Solder Kailh Hotswap sockets


Place the component, and hold it in place with tweezers. (The sockets can also be held in place by hand, but please take extra care not to burn yourself.)

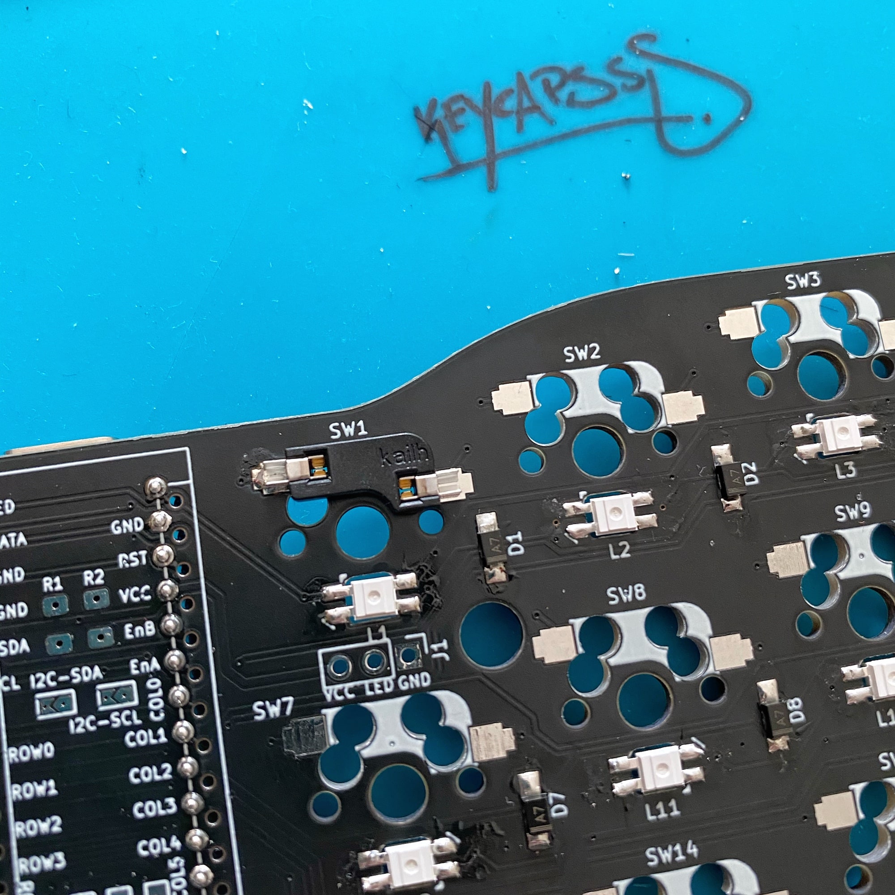
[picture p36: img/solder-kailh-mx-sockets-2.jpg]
Solder Kailh Hotswap sockets


> The sockets take **way** more solder than the other components like the LEDs and the diodes. But don't exaggerate...

## Case assembly

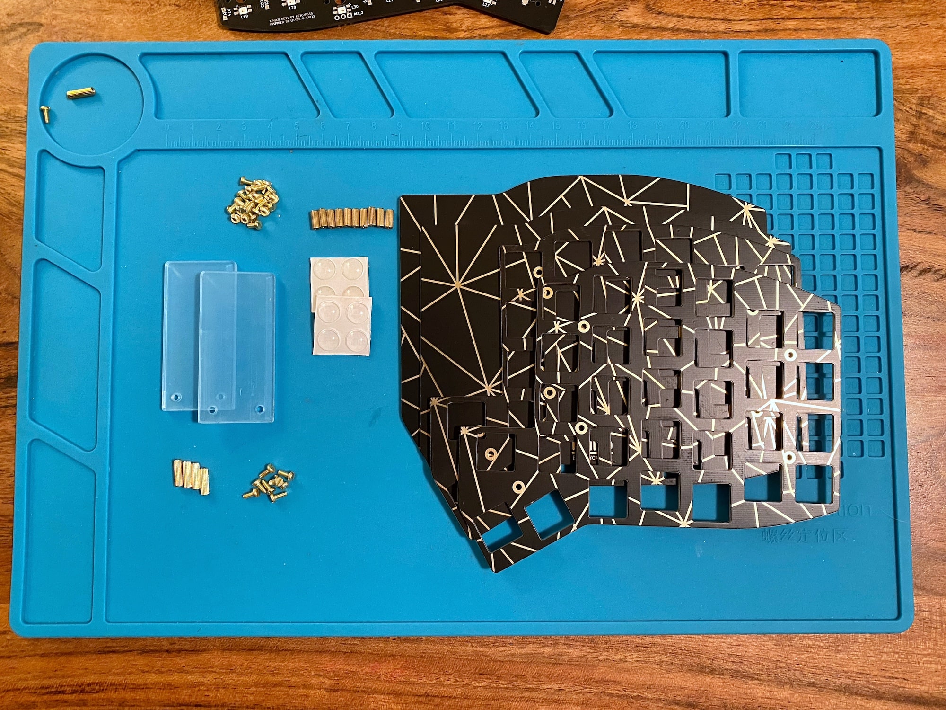
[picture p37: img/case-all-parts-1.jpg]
case parts overview


### Attach the spacer

Attach two **10mm spacers** to the holes near TRRS jack with the **5mm screws**.
It's easy to insert a screw from the back of the board and attach the spacer from the top.

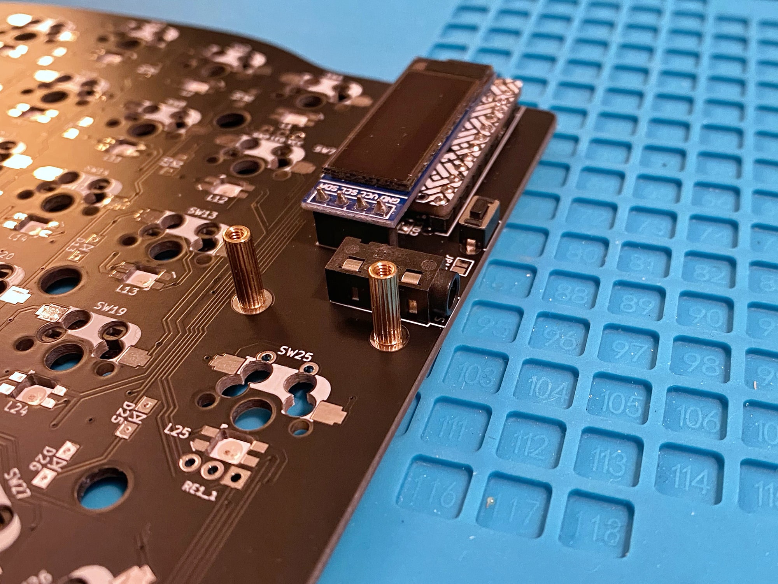
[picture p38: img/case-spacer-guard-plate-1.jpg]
Spacer for oled guard plate


Attach the **7mm spacer** to the top plate. If your kit comes with washers attached those to the spacers (They will hold the top plate slightly off the PCB)

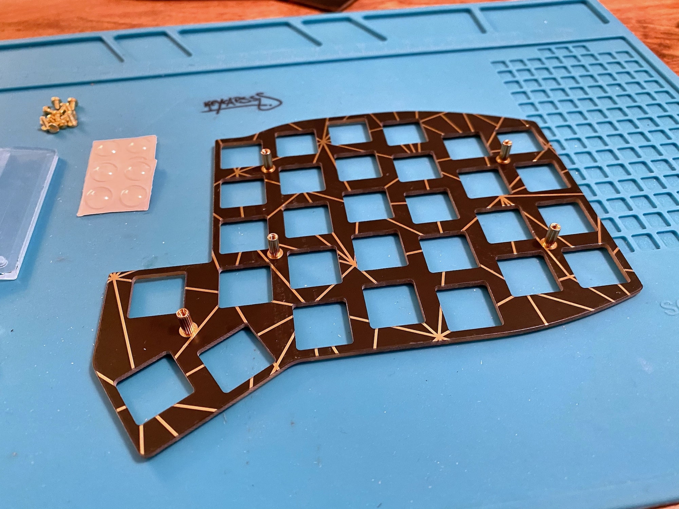
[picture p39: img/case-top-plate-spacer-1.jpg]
Top plate 7mm spacer


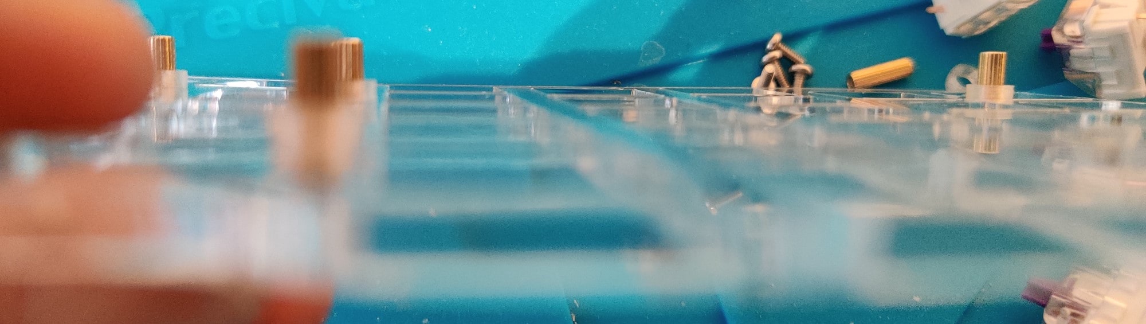
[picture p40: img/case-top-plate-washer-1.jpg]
Top plate washer

*Spacer washer for acrylic case (not necessary for FR4 plate case).*

### Prepare the rotary encoder

Remove the alignment legs on the rotary encoder with diagonal pliers.

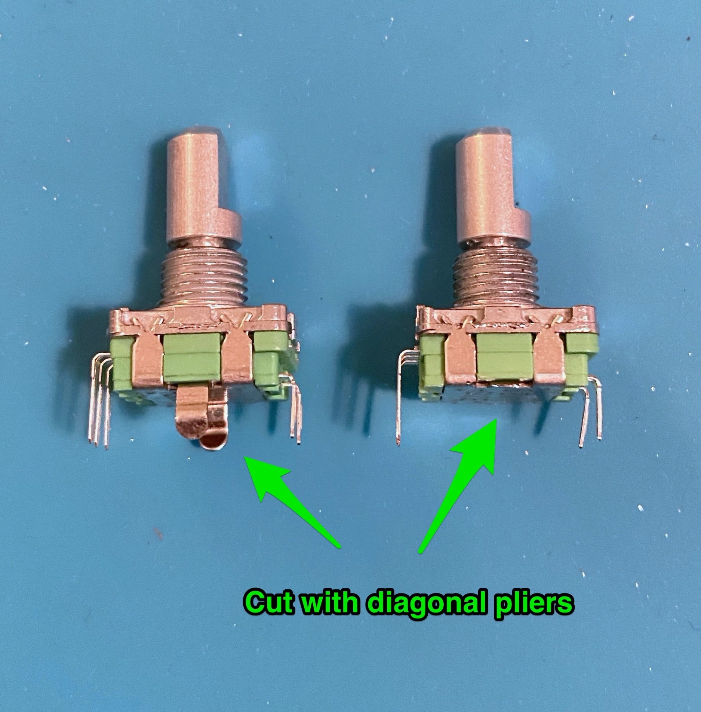
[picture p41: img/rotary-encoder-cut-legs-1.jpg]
Rotary encoder cut legs


If your rotary encoder has a metal surface at the bottom, cover it with some isolation tape, to prevent shorts on the LED pads.

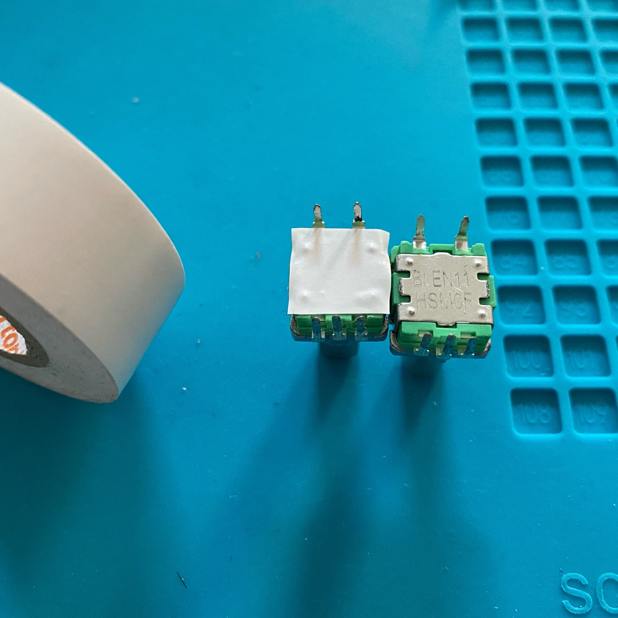
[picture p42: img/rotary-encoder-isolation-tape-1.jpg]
Rotary encoder isolation tape


You can place one encoder per side, or leave it empty and place a switch at this position.

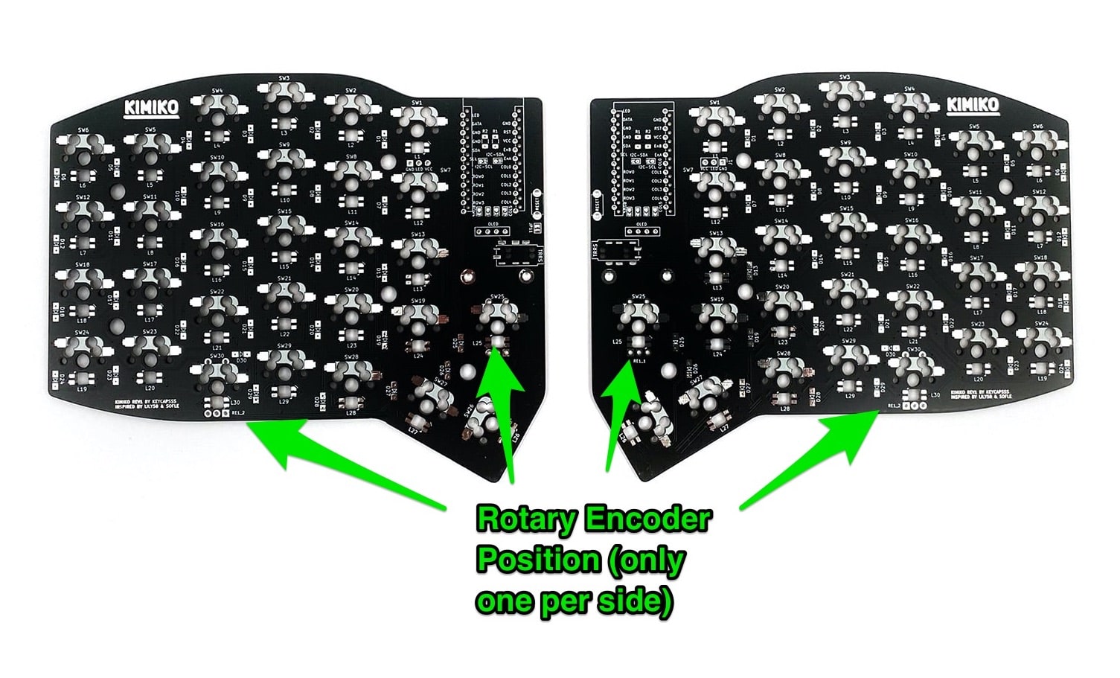
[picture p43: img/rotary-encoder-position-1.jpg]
Rotary encoder position


**Do not solder the rotary encoder at this point.** If it sits loose on the mid pcb, the clearance helps that the encoder fits in the top plate hole.

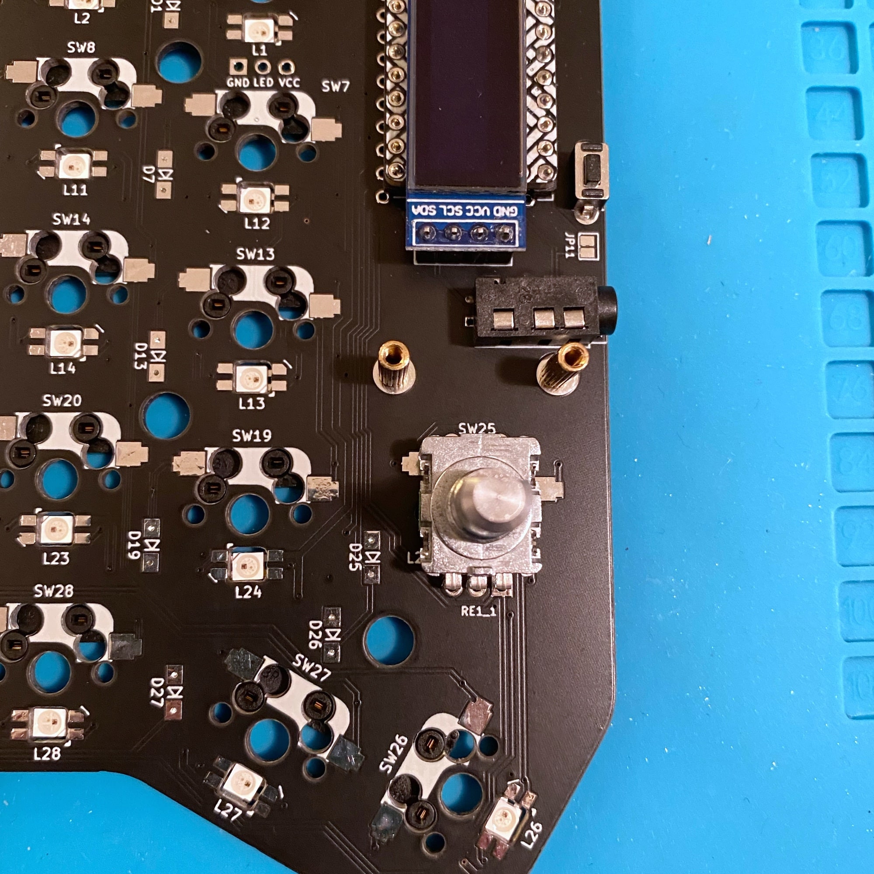
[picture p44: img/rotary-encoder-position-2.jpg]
Rotary encoder positions


### Attach the key switch

Attach four key switches to the top plate. The hole for the switch led is facing down.

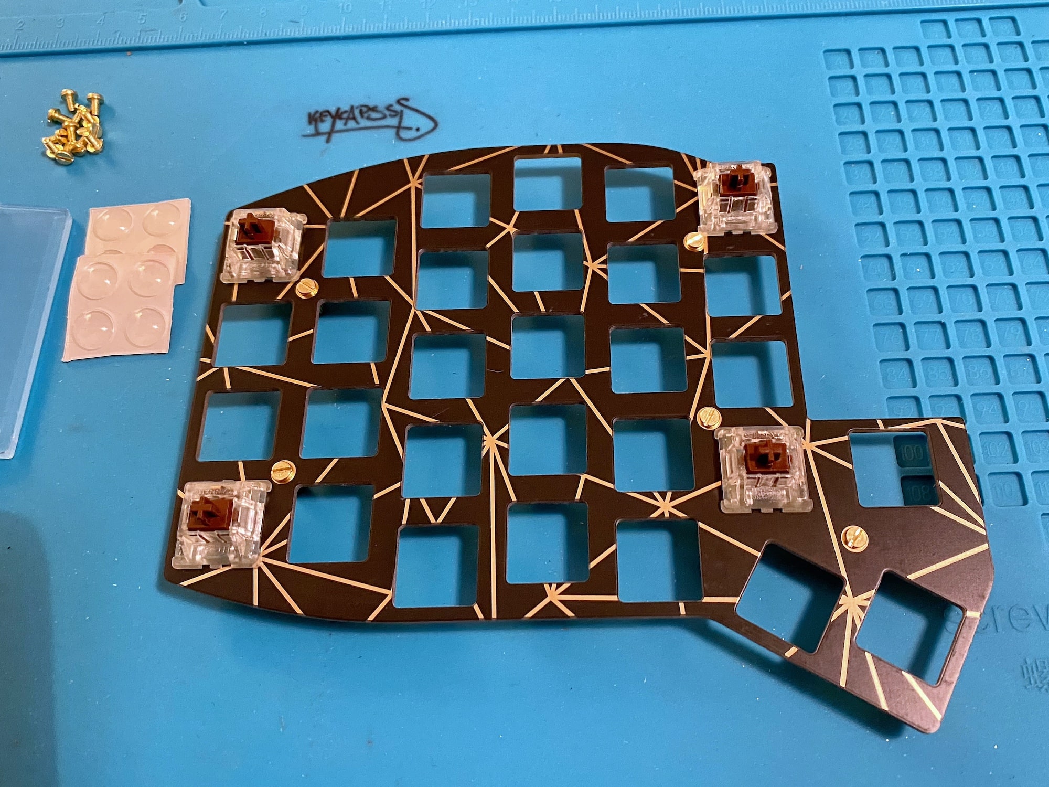
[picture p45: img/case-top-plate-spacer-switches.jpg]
Top plate with 4 switches


It's important that the switch pins are not bend.

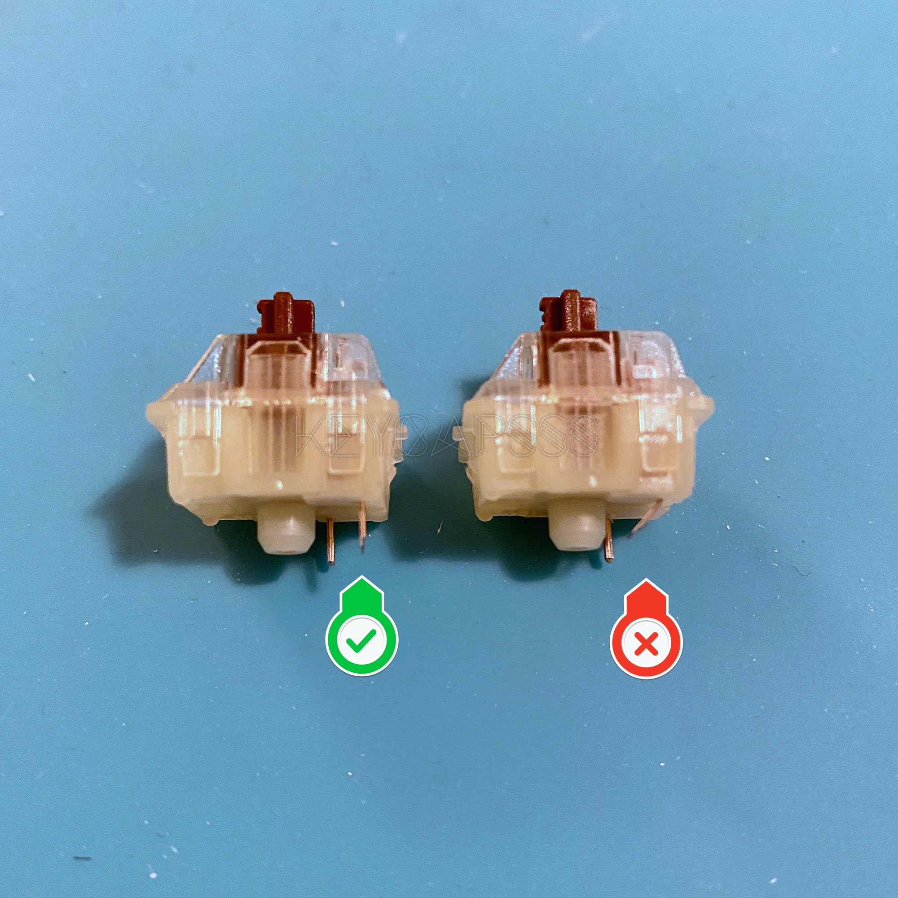
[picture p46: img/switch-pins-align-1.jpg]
Switch pin align


Insert the switch into the board for alignment, and line up the components.

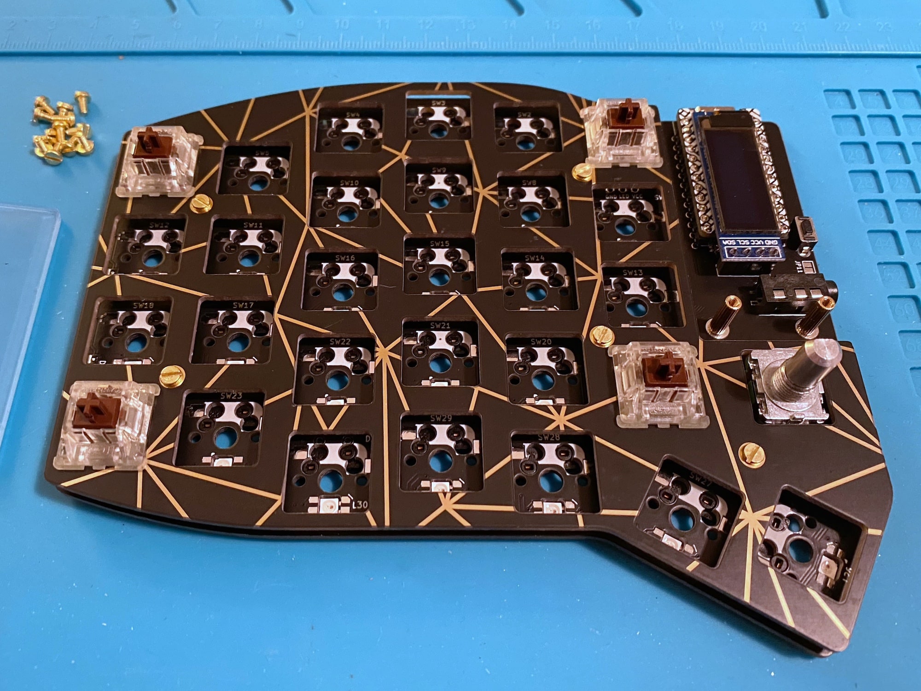
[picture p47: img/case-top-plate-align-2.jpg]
Top plate

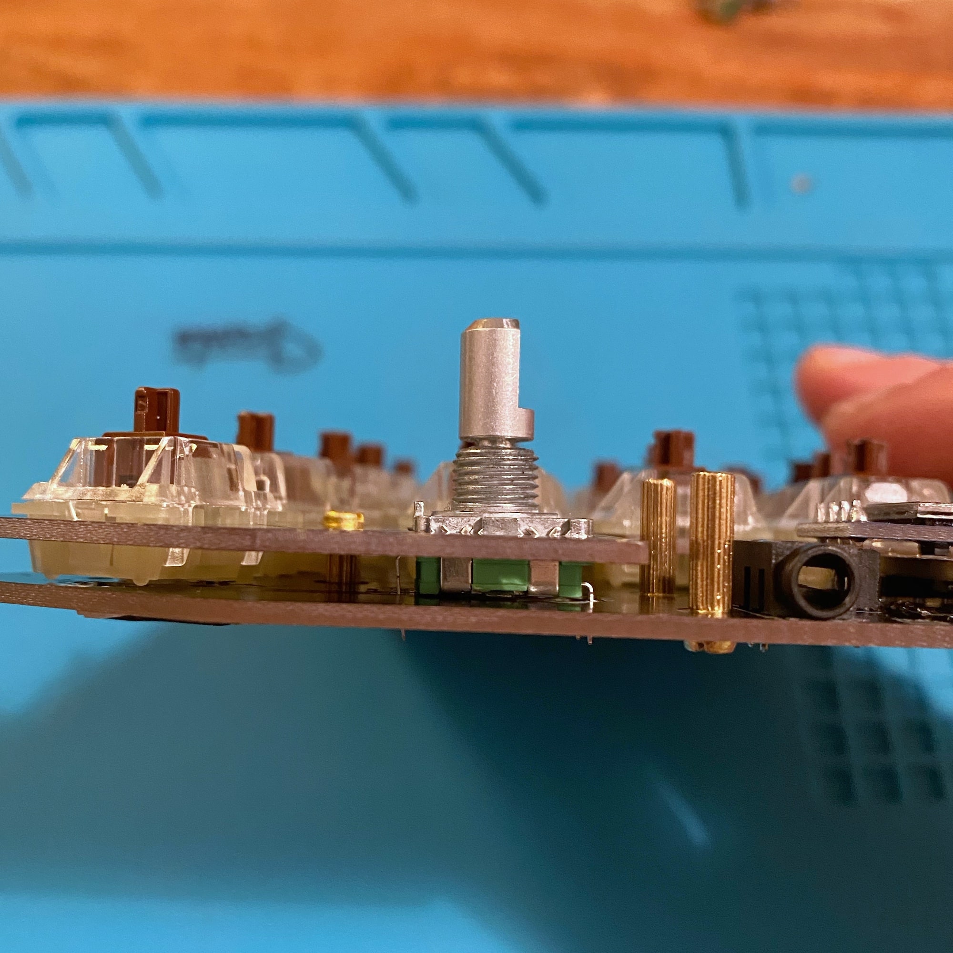
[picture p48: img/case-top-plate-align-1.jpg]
Top plate align


After confirming that there are no bends in the switch pins, you can attach it firmly by starting from the middle row and working outward.
Be careful: some switches require some power for installation.
Always be careful to put the switches in nice and straight, otherwise you'll bend the pins and scratch the PCB.
After mounting the plate, push the switches again to make sure that installation is complete.

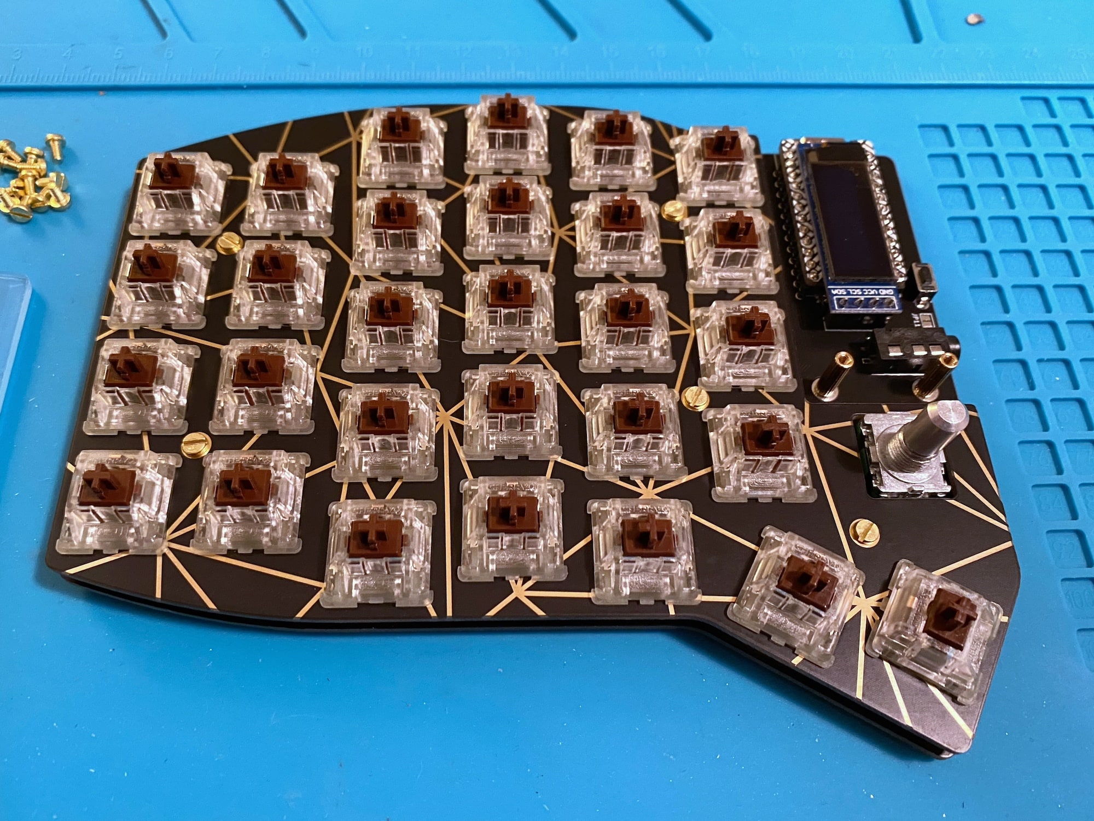
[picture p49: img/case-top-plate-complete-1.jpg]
Top plate complete with switches


Confirm that the rotary encoder sits straight on the PCB.  
Solder the 5 points.

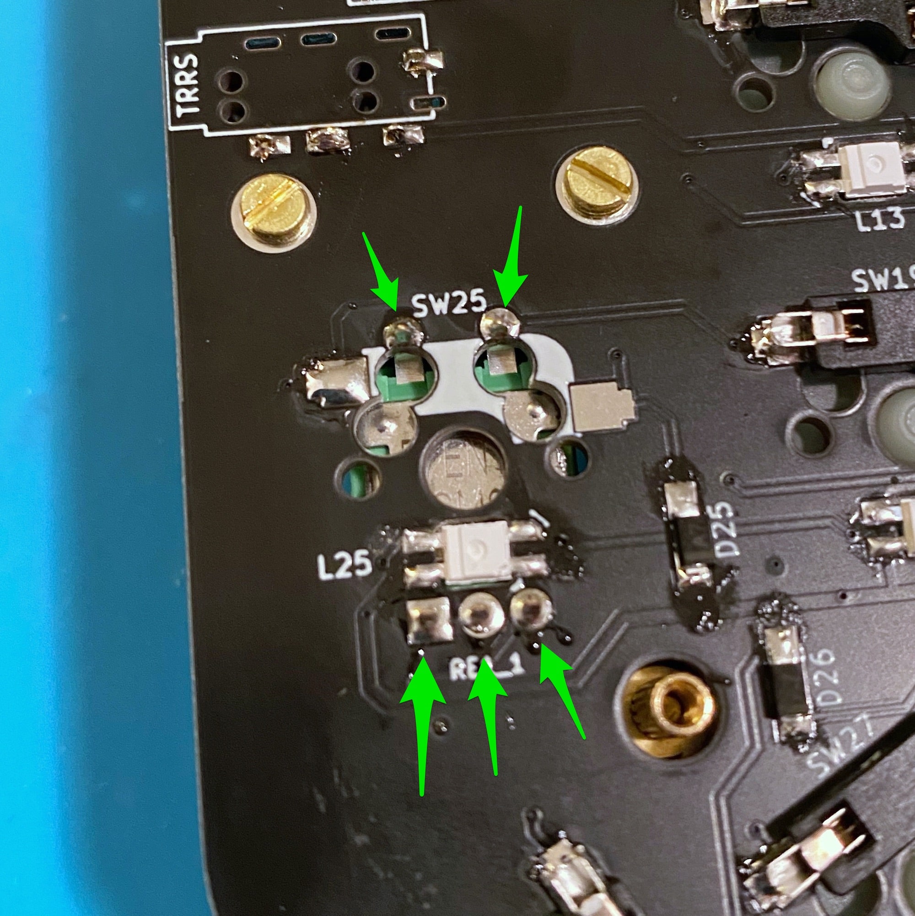
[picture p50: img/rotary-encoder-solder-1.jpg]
Solder the rotary encoder


Soldering the rotary encoder is as simple as any other component. Put the encoder from the front into the holes on the PCB, just below the screen, and solder it from the back.

**Tip** Depending on your case you should first try and bend the rotary encoder legs a bit before soldering it in. The legs can prevent your case from closing completly, as it will rest on the protruding legs. Bending the pins so that they are flush with the encoder helps here. (you can also just clip them off)

> **For your information.** The top **two** legs serve as a simple connection that is closed by the rotary encoders tactile press. It's connected to the pins a switch would be connected to, if there were on in the place of the rotary encoder. Therefore, in your firmware the rotary encoder will behave as a normal keyswitch in the matrix.

The lower three pins do the actual rotary-encoding part

### Pro Micro protective acrylic installation

Peel off the protective plastic layer covering the acrylic.  
Antistatic spray helps to counteract that the cover is a dust magnet. I use [Velind Antistatik Spray](https://amzn.to/2ZMTz93)**affiliate link*

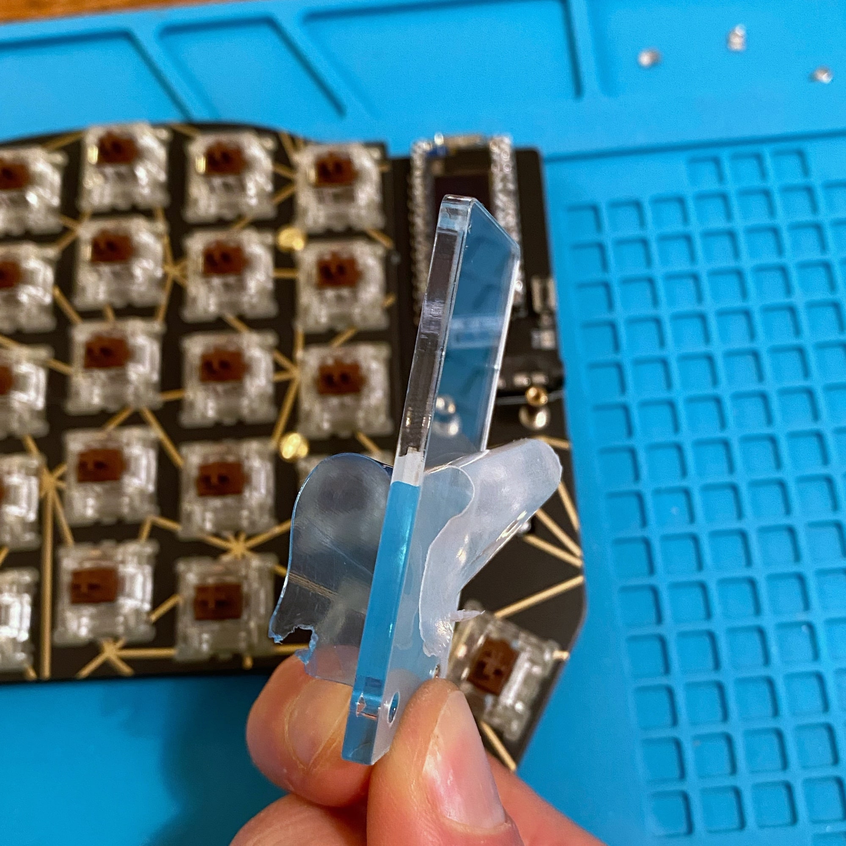
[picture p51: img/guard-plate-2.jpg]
Guard plate protective film


Attach the acrylic plate to the board with 5mm screws.

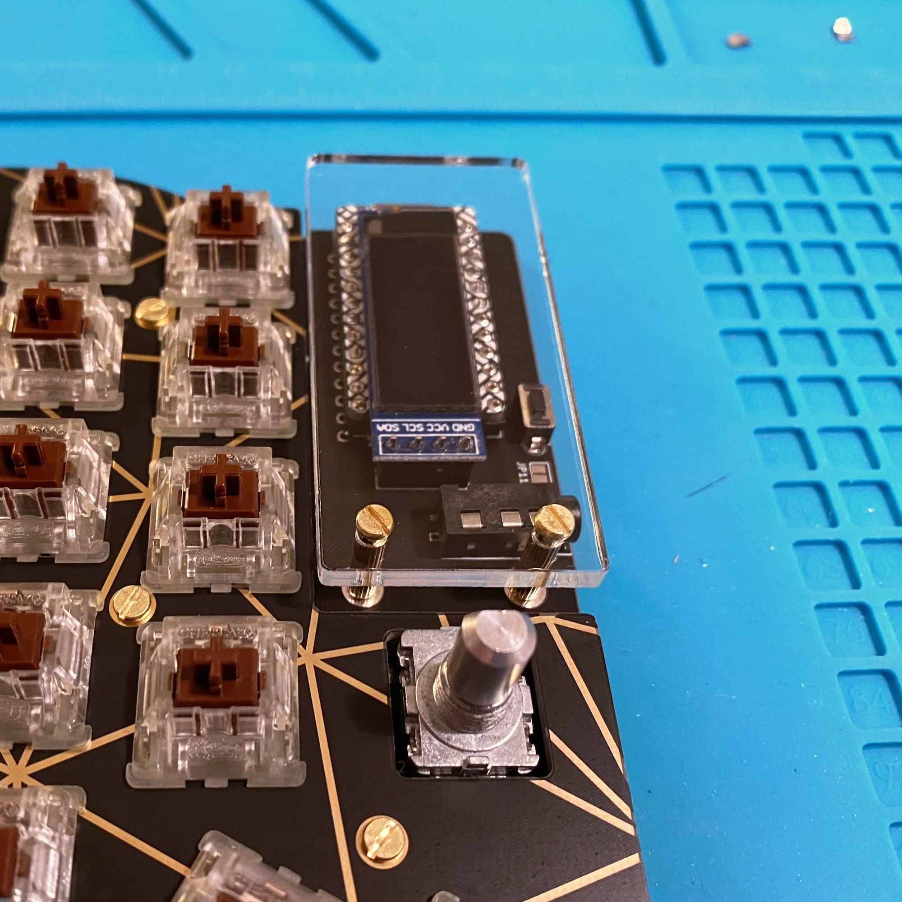
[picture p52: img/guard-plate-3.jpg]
Guard plate

Guard plate

### Assemble the bottom plate

To complete the case, attach the bottom plate with 5 screws and stick the 4 rubber feeds to the corners.

Bottom plate

Your Kimiko keyboard is now complete.

Proud

## Flash keymap on Pro Micro/Puchi-C

The board requires a [keymap](https://github.com/qmk/qmk_firmware/tree/master/keyboards/keycapsss/kimiko) in order to function. This section assumes that you're familiar with keymaps and the use of the QMK tool. If not, please refer to [the QMK "Getting Started" guide](https://docs.qmk.fm/#/getting_started_build_tools) (Windows: MSYS2; Mac, Linux: avrdude)

The [QMK Toolbox](https://github.com/qmk/qmk_toolbox/releases) can be used to write non-customized keymaps via a GUI, avoiding the need to configure a local QMK environment. (For custom keymaps/rotary encoder behavior, it's recommended to build the full environment described above).

Clone/download the QMK firmware and execute the following in the [qmk_firmware](https://github.com/qmk/qmk_firmware) directory to write the default Lily58L keymap

```bash
make keycapsss/kimiko:default:avrdude
```

When **`Detecting USB port, reset your controller now...`** is displayed, press the reset button on the keyboard to start writing.
Each half of the keyboard must be programmed separately using this approach.

If you're using DFU bootloader (in case of the Puchi-C/Elite-C), replace the `avrdude` with `dfu`.

### Congratulations 🥳

If everything works: You have built your Kimiko. Have fun!
[If something doesn't work](#troubleshooting)

## Customize the default keymap

**[Keymap-Guide](Keymap.md)**

## Troubleshooting

### Q. One or more rows/columns of key switches do not respond

A. The Pro Micro board may not be soldered and attached firmly. Check again, and re-solder and reinstall if necessary.

### Q. A single key switch doesn't respond

A. There may be a problem with the key switch's insertion, socket or diode soldering.

In the case of bad key switch insertion:
After removing the key switch, make sure that the pins aren't bent, and then push it in again and install it.

In the case of badly attached socket:
Re-solder the problem socket, or reflow and add solder if the joint is weak.
  
In the case of badly attached diode:
Check the [direction of the diode](#attach-the-diodes) in question. If it is wrong, remove it and re-solder it. Additionally, if there isn't enough solder, please re-solder.

### Q. Both half‘s are working as single, but if i connect them via TRRS cable one side is not working.

A. Check the TRRS jack solder points for bridges or cold solder points.

The TRRS cable should have 4 poles.

Use a multimeter to check the cable. Each pole should only have connection to the opposite pole.

### Q. One side does not respond.

A. Check if all LED‘s have the correct orientation.

### Q. A symbol different from the symbol input by "@" or "[" etc. is input (on Windows, etc.)

A. Please set OS Keyboard Layout as a US keyboard in the OS keyboard settings.

**If you have any problems, please feel free to send a message on Discord (<https://discord.gg/frjFXZB>) or Twitter: [@keycapsss](https://twitter.com/keycapsss)**

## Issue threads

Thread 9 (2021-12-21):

RGB underglow color does not change

Roycinger, 2021-12-21:
Hi,

I successfully soldered up a Kimiko.
Going after the guide for a custom keymap, I wanted to start with another underglow color as a first test.
As stated, I copied the folder "\qmk_firmware\keyboards\keycapsss\kimiko\keymaps\default" to "\qmk_firmware\keyboards\keycapsss\kimiko\keymaps\test" and edited the config.h in there:
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
In my opinion, this should change the underglow color to a somewhat greenish color.
After reflashing the Arduino Pro Micro with "make keycapsss/kimiko:test:avrdude", the underglow color still stays red like after the initial first flash of the Arduino.

Am I missing something here?
Any help is appreciated.

Roycinger, 2021-12-22:
Missed to set RGBLIGHT_DEFAULT_HUE, issue is resolved

Closed 2021-12-22.

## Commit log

2021-02-16 fix led img link
2021-02-20 add instructions for the case
2021-02-21 add encoder isolation tape instructions
2021-05-15 Update readme and add plate drawings
    [kimiko-plate-bottom.dwg, kimiko-plate-top.dxf]
2021-05-27 Table of instructions, Clear Instructions on PCB Installation (#3)
    * Update README.md
    * Add table of contents
    * Create Keymap.md
    * Add Keymap guide
    * Update buildguide_en.md
    * Update instructions for pro micro installation
    * Upload images for pro micro installation
    * Update pro micro installation steps with images
    * Minor fix
    * Update buildguide_en.md
    * Update buildguide_en.md
    Added washer information
    * fix: typo
    * fix: image file naming
    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
2021-08-24 Update buildguide_en.md (#4)
    Add an explicit explanation for LED orientation.
2021-10-26 Add Kimiko tenting plates by TRothfelder (#8)
    * Add Kimiko tenting plate
    * Add Kimiko tenting case
    Deleted old case files and added new ones which contain the whole case.
    Top, Bottom and Display files are now added to the repo.
    * Add bottom without distance holders
    Added readme and bottom part without distance holders.
    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
    [kimiko_keyboard_case_tenting.FCStd, kimiko_keyboard_case_tenting.stl, kimiko_keyboard_case_tenting_PartBottom.step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]
2021-10-26 add creator name to tenting case folder
    [kimiko_keyboard_case_tenting.FCStd, kimiko_keyboard_case_tenting.stl, kimiko_keyboard_case_tenting_PartBottom.step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]
2021-10-26 move default case files to cad folder
    [kimiko-plate-bottom.dwg, kimiko-plate-bottom.dxf, kimiko-plate-top.dxf]
2022-07-09 add cad files for guard plate and foam bottom
    [foam-bottom.dxf, plate-guard.dxf]

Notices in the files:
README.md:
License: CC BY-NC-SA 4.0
